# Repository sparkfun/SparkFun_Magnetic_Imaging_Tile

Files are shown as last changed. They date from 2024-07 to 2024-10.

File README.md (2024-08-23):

SparkFun Magnetic Imaging Tile - 8x8
========================================

SparkFun Magnetic Imaging Tile (https://www.sparkfun.com/products/26092)

[*SparkFun Magnetic Imaging Tile - 8x8 (SEN-26092)*](https://www.sparkfun.com/products/26092)

The Magnetic Imaging Tile uses an array of 64 hall effect sensors to convert magnetic fields to the visual spectrum. That's right! You can now see magnetic fields in real time! As is to be expected, there are caveats: the magnetic sensors used on the tile are some of the most sensitive on the market but you need to be within 1 to 2 centimeters of the tile to get a good image.

This is a board intended to function as a "magnetic field camera" to visualize magnetic fields.

This is an endorsed fork and collaboration of [Peter Jansen's work](https://hackaday.io/project/18518-iteration-8/log/91551-a-third-high-speed-magnetic-imager-tile). All credit goes to him! SparkX has re-designed the PCB for DFM and simplified some of the platform interfacing code.

### Version 3.0

The major advancement of v3.0 is a dramatic increase in the speed with which the tile data can be read out. ~2000 frames per second (fps) can be achieved which allows visualizing even quickly varying fields (e.g. those in a 60Hz transformer, or a moving motor). Version 3.0 reduces the size of the tile to an 8x8 grid of hall effect sensors (64 total), arrayed in a 4mm grid.  The boards is tile-able with up to 4 of the boards tileable with minimal borders to create a 16x16 array.

For more information (and a video of the v3.0 tile in use), please see:
https://hackaday.io/project/18518-iteration-8/log/91551-a-third-high-speed-magnetic-imager-tile-draft

Repository Contents
-------------------
* **.github/workflows** - YAML files used for GitHub Actions and GitHub Pages/mkdocs
* **/Hardware** - Eagle design files (.brd, .sch)
* **/Production** - Production panel files (.brd)
* **/Software** - Related software for the Magnetic Imaging Tile
* **/docs** - Online documentation files
  * **/assets** - Folder containing all the file assets used for product documentation
    * **/board_files** - Copy of design files used for product documentation
    * **/component_documentation** - Datasheets and manuals for hardware components
    * **/img** - Images for product documentation
  * **/github** - Files stating how to contribute and filing issues used for product documentation
  * **/javascript** - Folder containing custom javascript used for product documentation
  * **/stylesheet** - Folder containing CSS files used for product documentation
* **/overrides** - Customization files used for product documentation
  * **/.icons** - Icons used for GitHub used for product documentation
  * **./partials** - Used for product documentation

License Information
-------------------

This product is _**open source**_!

Please review the LICENSE.md file for license information.

If you have any questions or concerns on licensing, please contact technical support in our [SparkFun forums](https://community.sparkfun.com/c/community/general-chit-chat/37.)

Please use, reuse, and modify these files as you see fit. Please maintain attribution to SparkFun Electronics and release any derivative under the same license.

Disclaimer
-------------------

**DISCLAIMER OF WARRANTIES AND LIMITATION OF LIABILITY.**

UNLESS OTHERWISE SEPARATELY UNDERTAKEN BY THE LICENSOR, TO THE EXTENT POSSIBLE, THE LICENSOR OFFERS THE LICENSED MATERIAL AS-IS AND AS-AVAILABLE, AND MAKES NO REPRESENTATIONS OR WARRANTIES OF ANY KIND CONCERNING THE LICENSED MATERIAL, WHETHER EXPRESS, IMPLIED, STATUTORY, OR OTHER. THIS INCLUDES, WITHOUT LIMITATION, WARRANTIES OF TITLE, MERCHANTABILITY, FITNESS FOR A PARTICULAR PURPOSE, NON-INFRINGEMENT, ABSENCE OF LATENT OR OTHER DEFECTS, ACCURACY, OR THE PRESENCE OR ABSENCE OF ERRORS, WHETHER OR NOT KNOWN OR DISCOVERABLE. WHERE DISCLAIMERS OF WARRANTIES ARE NOT ALLOWED IN FULL OR IN PART, THIS DISCLAIMER MAY NOT APPLY TO YOU.

TO THE EXTENT POSSIBLE, IN NO EVENT WILL THE LICENSOR BE LIABLE TO YOU ON ANY LEGAL THEORY (INCLUDING, WITHOUT LIMITATION, NEGLIGENCE) OR OTHERWISE FOR ANY DIRECT, SPECIAL, INDIRECT, INCIDENTAL, CONSEQUENTIAL, PUNITIVE, EXEMPLARY, OR OTHER LOSSES, COSTS, EXPENSES, OR DAMAGES ARISING OUT OF THIS PUBLIC LICENSE OR USE OF THE LICENSED MATERIAL, EVEN IF THE LICENSOR HAS BEEN ADVISED OF THE POSSIBILITY OF SUCH LOSSES, COSTS, EXPENSES, OR DAMAGES. WHERE A LIMITATION OF LIABILITY IS NOT ALLOWED IN FULL OR IN PART, THIS LIMITATION MAY NOT APPLY TO YOU.

THE DISCLAIMER OF WARRANTIES AND LIMITATION OF LIABILITY PROVIDED ABOVE SHALL BE INTERPRETED IN A MANNER THAT, TO THE EXTENT POSSIBLE, MOST CLOSELY APPROXIMATES AN ABSOLUTE DISCLAIMER AND WAIVER OF ALL LIABILITY.

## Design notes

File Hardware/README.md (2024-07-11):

SparkFun <PRODUCT NAME> Design Files
=====================================

The .sch and .brd files hare are Eagle CAD schematic and PCB design files from SparkFun Electronics.
A freeware version of Autodesk Eagle can be found [here](https://www.autodesk.com/products/eagle/free-download).

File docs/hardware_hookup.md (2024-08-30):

### Connecting via PTH

For temporary connections to the PTHs, you could use IC hooks to test out the pins. However, you'll need to solder headers or wires of your choice to the board for a secure connection. You can choose between a combination of [header pins and jumper wires](https://learn.sparkfun.com/tutorials/how-to-solder-through-hole-soldering/all), or [stripping wire and soldering the wire](https://learn.sparkfun.com/tutorials/working-with-wire/all) directly to the board.

<div class="grid cards col-2" markdown>

-   <a href="https://learn.sparkfun.com/tutorials/how-to-solder-through-hole-soldering/all">
      <figure markdown>
        How to Solder: Through Hole Soldering
      </figure>
    </a>

    ---

    <a href="https://learn.sparkfun.com/tutorials/how-to-solder-through-hole-soldering/all">
      <b>How to Solder: Through Hole Soldering</b>
    </a>
<!-- ----------WHITE SPACE BETWEEN GRID CARDS---------- -->

-   <a href="https://learn.sparkfun.com/tutorials/working-with-wire/all">
      <figure markdown>
        Working with Wire
      </figure>
    </a>

    ---

    <a href="https://learn.sparkfun.com/tutorials/working-with-wire/all">
      <b>Working with Wire</b>
    </a>
<!-- ----------WHITE SPACE BETWEEN GRID CARDS---------- -->
</div>

For the scope of this tutorial, we will use right angle, male headers. Insert the right angle headers on the top side and solder the header pins from the bottom. Of course, you can also insert the right angle header so that the pins face toward the multiplexors similar to Peter's demo video.

<div style="text-align: center;">
  <table>
    <tr style="vertical-align:middle;">
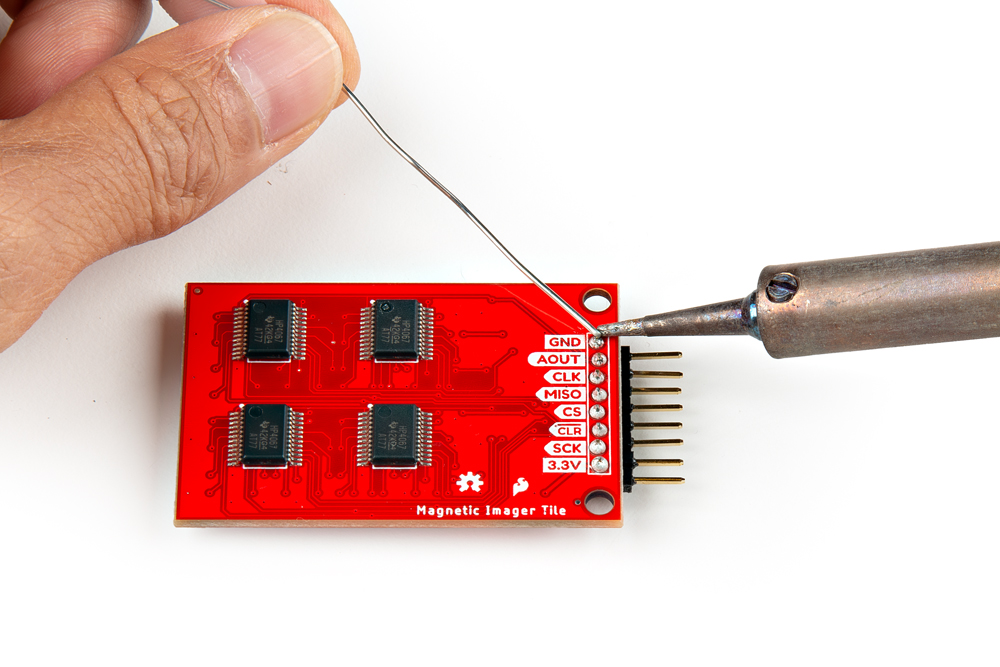
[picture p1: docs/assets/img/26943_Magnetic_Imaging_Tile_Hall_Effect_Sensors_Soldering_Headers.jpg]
Headers Being Soldered to the Magnetic Imaging Tile
     <td style="text-align: center; vertical-align: middle; border: solid 1px #cccccc;"></td>
    </tr>
    <tr style="vertical-align:middle;">
     <td style="text-align: center; vertical-align: middle; border: solid 1px #cccccc;"><i>Headers Being Soldered to the Magnetic Imaging Tile</i></td>
    </tr>
  </table>
</div>

<div style="text-align: center;">
    <table>
        <tr>
            <th style="text-align: center; border: solid 1px #cccccc;">Magnetic Imaging<br />Tile Pinout
            </th>
            <th style="text-align: center; border: solid 1px #cccccc;"> SAMD21 Pinout<br />(i.e. RedBoard Turbo, SAMD21 Mini, etc.)
            </th>
            <th style="text-align: center; border: solid 1px #cccccc;"> Teensy Pinout<br />(i.e. Teensy v3.1, v3.5, v4.0, v4.1, etc.)
            </th>
            <th style="text-align: center; border: solid 1px #cccccc;"> SAMD51 Pinout<br />(i.e. SAMD51 Thing Plus, etc.)
            </th>
        </tr>
        <tr>
            <td style="text-align: center; border: solid 1px #cccccc;" bgcolor="#DDDDDD"><font color="#000000">GND</font>
            </td>
            <td style="text-align: center; border: solid 1px #cccccc;" bgcolor="#DDDDDD"><font color="#000000">GND</font>
            </td>
            <td style="text-align: center; border: solid 1px #cccccc;" bgcolor="#DDDDDD"><font color="#000000">GND</font>
            </td>
            <td style="text-align: center; border: solid 1px #cccccc;" bgcolor="#DDDDDD"><font color="#000000">GND</font>
            </td>
        </tr>
        <tr>        
            <td style="text-align: center; border: solid 1px #cccccc;" bgcolor="#cce5ff"><font color="#000000">OUT</font>
            </td>
            <td style="text-align: center; border: solid 1px #cccccc;" bgcolor="#cce5ff"><font color="#000000">A1</font>
            </td>
            <td style="text-align: center; border: solid 1px #cccccc;" bgcolor="#cce5ff"><font color="#000000">A1</font>
            </td>
            <td style="text-align: center; border: solid 1px #cccccc;" bgcolor="#cce5ff"><font color="#000000">A1</font>
            </td>
        </tr>
        <tr>
            <td style="text-align: center; border: solid 1px #cccccc;" bgcolor="#fff3cd"><font color="#000000">SCK</font>
            <td style="text-align: center; border: solid 1px #cccccc;" bgcolor="#fff3cd"><font color="#000000">13</font>
            </td>
            <td style="text-align: center; border: solid 1px #cccccc;" bgcolor="#fff3cd"><font color="#000000">13</font>
            </td>
            <td style="text-align: center; border: solid 1px #cccccc;" bgcolor="#fff3cd"><font color="#000000">24</font>
            </td>
        </tr>
        <tr>
            <td style="text-align: center; border: solid 1px #cccccc;" bgcolor="#d4edda"><font color="#000000">MISO</font>
            </td>
            <td style="text-align: center; border: solid 1px #cccccc;" bgcolor="#d4edda"><font color="#000000">12</font>
            </td>
            <td style="text-align: center; border: solid 1px #cccccc;" bgcolor="#d4edda"><font color="#000000">12</font>
            </td>
            <td style="text-align: center; border: solid 1px #cccccc;" bgcolor="#d4edda"><font color="#000000">22</font>
            </td>
        </tr>
        <tr>
            <td style="text-align: center; border: solid 1px #cccccc;" bgcolor="#f2dede"><font color="#000000">CS</font>
            </td>
            <td style="text-align: center; border: solid 1px #cccccc;" bgcolor="#f2dede"><font color="#000000">10</font>
            </td>
            <td style="text-align: center; border: solid 1px #cccccc;" bgcolor="#f2dede"><font color="#000000">10</font>
            </td>
            <td style="text-align: center; border: solid 1px #cccccc;" bgcolor="#f2dede"><font color="#000000">10</font>
            </td>
        </tr>
        <tr>
            <td style="text-align: center; border: solid 1px #cccccc;" bgcolor="#ffffff"><font color="#000000">CLR</font>
            </td>
            <td style="text-align: center; border: solid 1px #cccccc;" bgcolor="#ffffff"><font color="#000000">8</font>
            </td>
            <td style="text-align: center; border: solid 1px #cccccc;" bgcolor="#ffffff"><font color="#000000">8</font>
            </td>
            <td style="text-align: center; border: solid 1px #cccccc;" bgcolor="#ffffff"><font color="#000000">5</font>
            </td>
        </tr>
        <tr>
            <td style="text-align: center; border: solid 1px #cccccc;" bgcolor="#ffdaaf"><font color="#000000">CLK</font>
            </td>
            <td style="text-align: center; border: solid 1px #cccccc;" bgcolor="#ffdaaf"><font color="#000000">9</font>
            </td>
            <td style="text-align: center; border: solid 1px #cccccc;" bgcolor="#ffdaaf"><font color="#000000">9</font>
            </td>
            <td style="text-align: center; border: solid 1px #cccccc;" bgcolor="#ffdaaf"><font color="#000000">9</font>
            </td>
        </tr>
        <tr>
            <td style="text-align: center; border: solid 1px #cccccc;" bgcolor="#f2dede"><font color="#000000">3.3V</font>
            </td>
            <td style="text-align: center; border: solid 1px #cccccc;" bgcolor="#f2dede"><font color="#000000">3V3</font>
            </td>
            <td style="text-align: center; border: solid 1px #cccccc;" bgcolor="#f2dede"><font color="#000000">3.3V</font>
            </td>
            <td style="text-align: center; border: solid 1px #cccccc;" bgcolor="#f2dede"><font color="#000000">3V3</font>
            </td>
        </tr>
    </table>
</div>

!!! note
    If you are using a development board with [updated SPI terminology](https://learn.sparkfun.com/tutorials/serial-peripheral-interface-spi/receiving-data), MISO may be labeled as POCI.

We will be using the RedBoard Turbo with female headers already installed on the board. For users that are using a different board, now would be a good time to solder headers or wires to the board. Below is an example with female headers soldered on the SAMD51 Thing Plus. Additionally, there are stackable headers soldered on the SAMD21 Mini Breakout so that the board can be inserted into a breadboard.

<div style="text-align: center;">
  <table>
    <tr style="vertical-align:middle;">
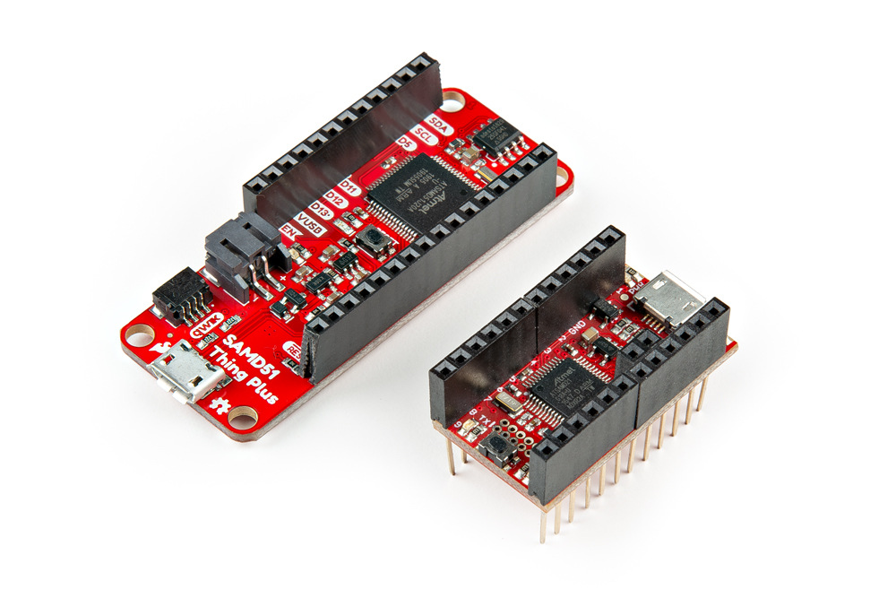
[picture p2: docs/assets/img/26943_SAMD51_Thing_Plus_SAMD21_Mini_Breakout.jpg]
Headers soldered on the SAMD51 Thing Plus and SAMD21 Mini Breakout
     <td style="text-align: center; vertical-align: middle; border: solid 1px #cccccc;"></td>
    </tr>
    <tr style="vertical-align:middle;">
     <td style="text-align: center; vertical-align: middle; border: solid 1px #cccccc;"><i>Headers soldered on the SAMD51 Thing Plus and SAMD21 Mini Breakout</i></td>
    </tr>
  </table>
</div>

### Connecting a Micrcontroller to the Magnetic Imaging Tile

We recommend using a microcontroller with sufficient RAM. While the example code can compile and function with Arduinos with an ATmega328P, the frames are limited. For the scope of the tutorial, we used a SAMD21. Of course, users can also use a Teensy and ChipKit as well.

Below is the Fritzing diagram of the RedBoard Turbo - SAMD21 connected to the Magnetic Imaging Tile.

<div style="text-align: center;">
  <table>
    <tr style="vertical-align:middle;">
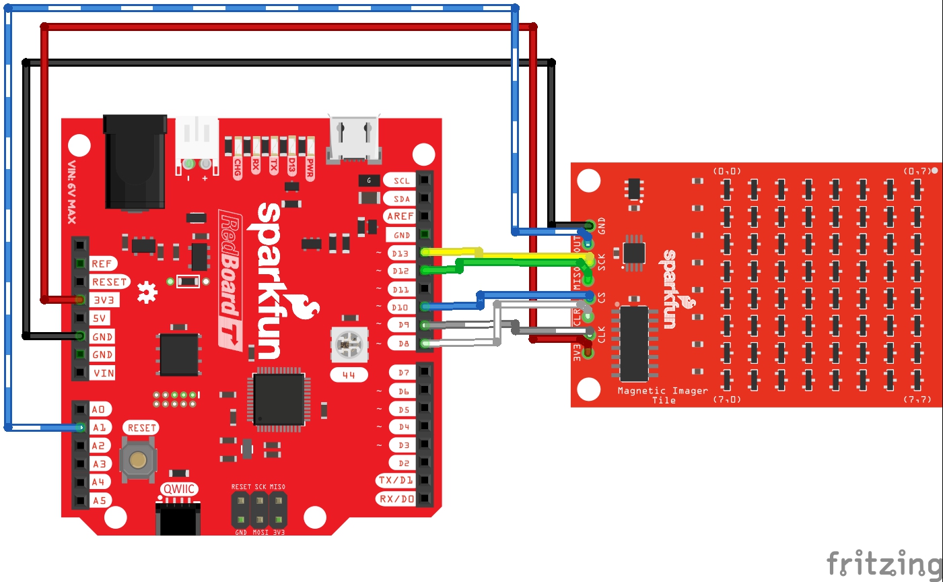
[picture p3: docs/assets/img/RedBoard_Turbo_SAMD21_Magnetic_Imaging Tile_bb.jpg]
Fritzing Diagram of RedBoard Turbo SAMD21 Connected to Magnetic Imaging Tile
     <td style="text-align: center; vertical-align: middle; border: solid 1px #cccccc;"></td>
    </tr>
    <tr style="vertical-align:middle;">
     <td style="text-align: center; vertical-align: middle; border: solid 1px #cccccc;"><i>Fritzing Diagram of RedBoard Turbo SAMD21 Connected to Magnetic Imaging Tile</i></td>
    </tr>
  </table>
</div>

After soldering headers to the Magnetic Imaging Tile, wire the board to the RedBoard Turbo using jumper wires. Then connect a micro-b USB cable to power and program the RedBoard Turbo.

<div style="text-align: center;">
  <table>
    <tr style="vertical-align:middle;">
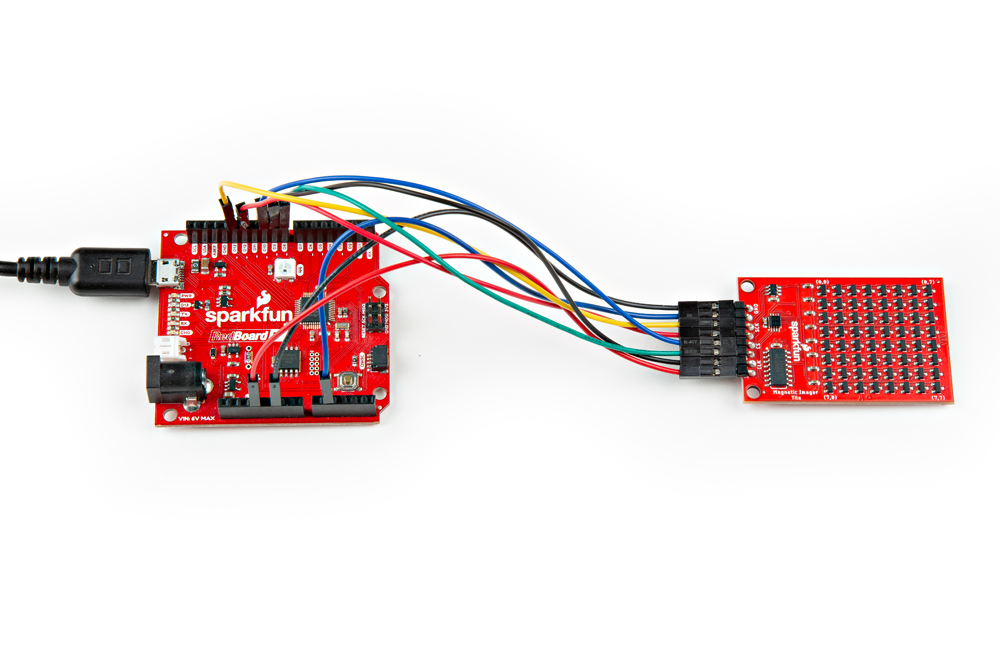
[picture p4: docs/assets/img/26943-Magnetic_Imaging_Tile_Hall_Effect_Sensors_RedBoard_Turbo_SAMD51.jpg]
RedBoard Turbo - SAMD21 Connected to Magnetic Imaging Tile
     <td style="text-align: center; vertical-align: middle; border: solid 1px #cccccc;"></td>
    </tr>
    <tr style="vertical-align:middle;">
     <td style="text-align: center; vertical-align: middle; border: solid 1px #cccccc;"><i>RedBoard Turbo - SAMD21 Connected to Magnetic Imaging Tile</i></td>
    </tr>
  </table>
</div>

You can also connected any SAMD21 to the Magnetic Imaging Tile. Below shows a Fritzing diagram of the SAMD21 Mini Breakout connected to the Magnetic Imaging Tile. When using other development boards, you may need to solder additional headers or wires to the board. Depending on the microcontroller, you may also need to redefine the pins in the Arduino example code in order to properly connect to the SPI port.

<div style="text-align: center;">
  <table>
    <tr style="vertical-align:middle;">
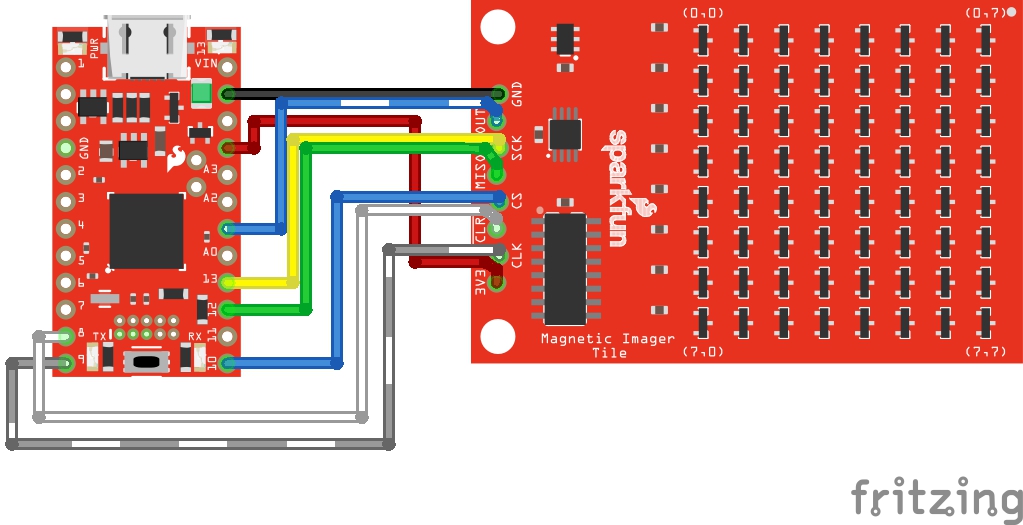
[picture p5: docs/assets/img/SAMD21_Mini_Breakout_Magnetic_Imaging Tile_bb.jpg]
Top View
     <td style="text-align: center; vertical-align: middle; border: solid 1px #cccccc;"></td>
    </tr>
    <tr style="vertical-align:middle;">
     <td style="text-align: center; vertical-align: middle; border: solid 1px #cccccc;"><i>Fritzing Diagram of SparkFun SAMD21 Mini Breakout Board Connected to Magnetic Imaging Tile</i></td>
    </tr>
  </table>
</div>

After soldering headers (or wires) on your microcontroller and Magnetic Imaging Tile, wire the boards together. The connect a micro-b USB cable to power and program the SAMD21 Mini Breakout.

<div style="text-align: center;">
  <table>
    <tr style="vertical-align:middle;">
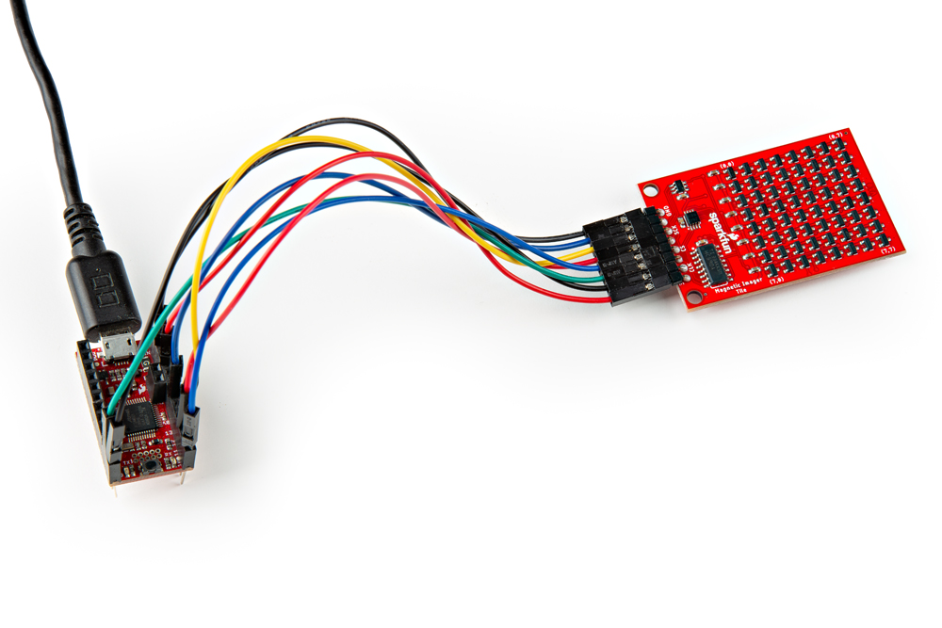
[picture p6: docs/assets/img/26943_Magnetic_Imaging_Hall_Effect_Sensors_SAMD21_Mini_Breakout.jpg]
SAMD21 Mini Breakout Connected to Magnetic Imaging Tile
     <td style="text-align: center; vertical-align: middle; border: solid 1px #cccccc;"></td>
    </tr>
    <tr style="vertical-align:middle;">
     <td style="text-align: center; vertical-align: middle; border: solid 1px #cccccc;"><i>SAMD21 Mini Breakout Connected to Magnetic Imaging Tile</i></td>
    </tr>
  </table>
</div>

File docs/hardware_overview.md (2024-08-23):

In this section, we will highlight the hardware and pins that are broken out on the SparkFun Magnetic Imaging Tile - 8x8. We'll refer to the "top" side of the board as the side with the 8x8 array of hall effect sensors. The "bottom" side of the board will be the side with the multiplexors. For more information, check out our [Resources and Going Further](../resources/) on the components used for the sensor.

<div style="text-align: center;">
  <table>
    <tr style="vertical-align:middle;">
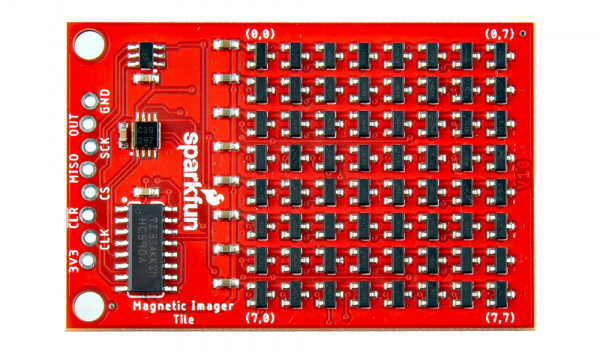
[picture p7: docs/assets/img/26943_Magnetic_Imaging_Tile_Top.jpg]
     <td style="text-align: center; vertical-align: middle; border: solid 1px #cccccc;"></td>
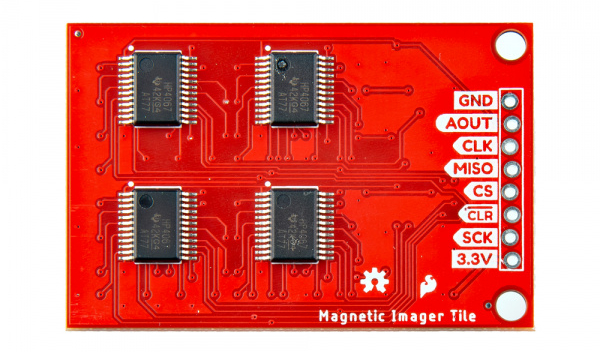
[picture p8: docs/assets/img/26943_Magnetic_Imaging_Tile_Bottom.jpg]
Bottom View
     <td style="text-align: center; vertical-align: middle; border: solid 1px #cccccc;"></td>
    </tr>
    <tr style="vertical-align:middle;">
     <td style="text-align: center; vertical-align: middle; border: solid 1px #cccccc;"><i>Top View</i></td>
     <td style="text-align: center; vertical-align: middle; border: solid 1px #cccccc;"><i>Bottom View</i></td>
    </tr>
  </table>
</div>

!!! note
    SparkX re-designed version 3.0's PCB for DFM and simplified some of the platform interfacing code. This design was transferred to SparkFun red and labeled as v1.0. Besides the color of the PCB and a few minor silkscreen changes, the boards are functionally the same.

    The major advancement of the current design (SparkX v3.0, SparkFun v1.0) is a dramatic increase in the speed with which the tile data can be read out. ~2000 frames per second (fps) can be achieved which allows visualizing even quickly varying fields (e.g. those in a 60Hz transformer, or a moving motor). Version 3.0 reduces the size of the tile to an 8x8 grid of hall effect sensors (64 total), arrayed in a 4mm grid. The boards is tile-able with up to 4 of the boards tile-able with minimal borders to create a 16x16 array.

!!! tip "What's with the zig zagging PTH's?"
    You may be wondering what is going on with the PTH. For those that have been around for a while, you might have noticed PTHs zig zagging on previous board designs. These offset PTHs are meant to "lock" header pins to the board to aid in soldering. For more information on the locking PTHs, check out the [Pete's "Sneaky Footprints"](https://www.sparkfun.com/tutorials/114)!

### Power

The 3.3V and ground are broken out on the edge of the board.

* **3V3** / **3.3V** &mdash; The 3.3V net is labeled as 3V3 or 3.3V. You can apply power to the board if you have a regulated voltage of 3.3V. Otherwise, you could power a separate device through the 3V3 PTH pin.
    * While the pin is labeled as 3.3V, you can also safely power the board with 5V as well. The components on the board can handle the voltage.
* **GND** &mdash; Of course, is the common, ground voltage (0V reference) for the system.

<div style="text-align: center;">
  <table>
    <tr style="vertical-align:middle;">
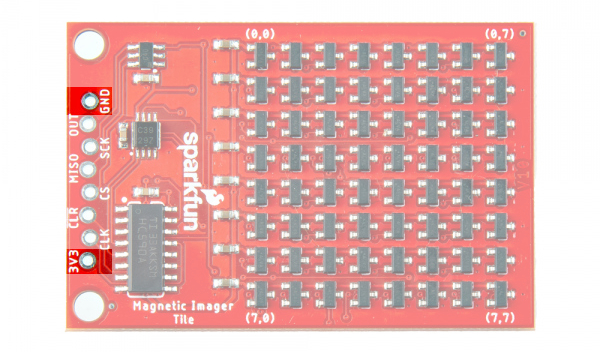
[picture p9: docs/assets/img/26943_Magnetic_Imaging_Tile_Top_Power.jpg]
Power and Ground Highlighted
     <td style="text-align: center; vertical-align: middle; border: solid 1px #cccccc;"></td>
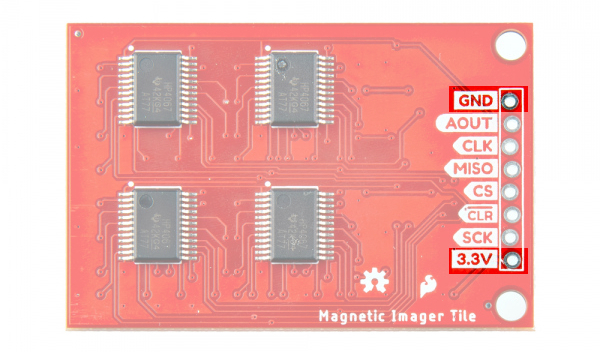
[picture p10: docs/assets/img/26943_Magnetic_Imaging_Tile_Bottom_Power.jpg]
Power and Ground Highlighted
     <td style="text-align: center; vertical-align: middle; border: solid 1px #cccccc;"></td>
    </tr>
    <tr style="vertical-align:middle;">
     <td style="text-align: center; vertical-align: middle; border: solid 1px #cccccc;" colspan="2"><i>Power and Ground Highlighted (Top & Bottom View)</i></td>
    </tr>
  </table>
</div>

### Hall Effect Sensors

The Magnetic Imaging Tile consists of 64x analog hall effect sensors arranged in an 8x8 grid. The specific hall effect sensor used is DRV5053VA with a sensitivity of -90mV/mT. The coordinates of each sensor is indicated by the silkscreen by the corners of the 8x8 array of hall effect sensors.

<div style="text-align: center;">
  <table>
    <tr style="vertical-align:middle;">
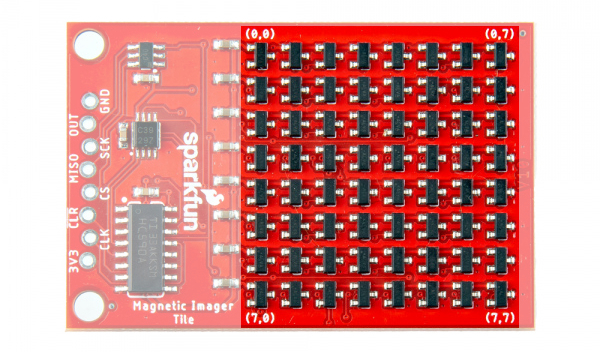
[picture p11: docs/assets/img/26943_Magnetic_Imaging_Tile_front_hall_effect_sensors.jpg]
Hall Effect Sensors Highlighted
     <td style="text-align: center; vertical-align: middle; border: solid 1px #cccccc;"></td>
    </tr>
    <tr style="vertical-align:middle;">
     <td style="text-align: center; vertical-align: middle; border: solid 1px #cccccc;"><i>Hall Effect sensors Highlighted/i></td>
    </tr>
  </table>
</div>

### Counter, Decoder, Muxes, and ADC

The circuit includes an SN74HC590A 8-bit binary counter (the 14-pin IC on the top of the board), SN74LVC1G139 decoder (the 8-pin IC on the top of the board), four CD74HC4067 multiplexors (the 4x ICs on the back of the board), and the AD7680 16-bit ADC (the 6-pin IC on the top of the board). Together (with some code loaded on a microcontroller), the components output the analog readings from the 64x hall effect sensors through SPI.

<div style="text-align: center;">
  <table>
    <tr style="vertical-align:middle;">
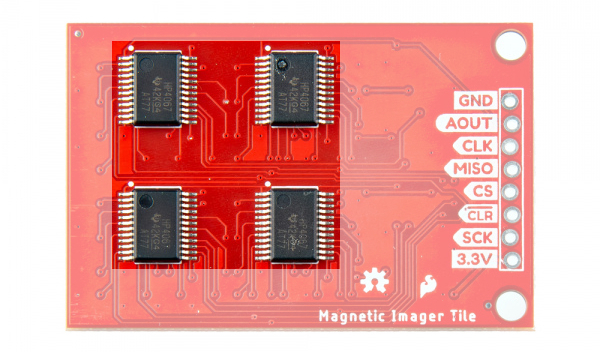
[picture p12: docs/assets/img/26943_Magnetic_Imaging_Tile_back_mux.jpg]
     <td style="text-align: center; vertical-align: middle; border: solid 1px #cccccc;"></td>
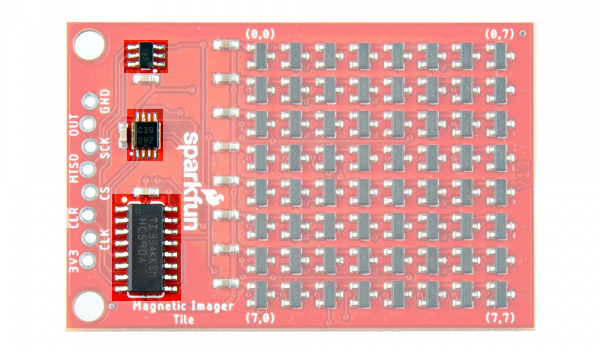
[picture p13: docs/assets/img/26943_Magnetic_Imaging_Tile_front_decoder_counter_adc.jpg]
     <td style="text-align: center; vertical-align: middle; border: solid 1px #cccccc;"></td>
    </tr>
    <tr style="vertical-align:middle;">
     <td style="text-align: center; vertical-align: middle; border: solid 1px #cccccc;"><i>Counter, Decoder, ADC Top View</i></td>
     <td style="text-align: center; vertical-align: middle; border: solid 1px #cccccc;"><i>Mux Bottom View</i></td>
    </tr>
  </table>
</div>

With a 16-bit ADC and a 3.3V range, this is approximately 50mV per bit. The Magnetic Imaging Tile is able to detect roughly +/- 0.5mT per bit. For our demo in the GIF we used a RedBoard Turbo with the SAMD21 to clock out the ADC data to the serial port at 115200. The serial is then parsed by a Processing sketch. This setup can achieve over 76 frames per second. With buffering the setup is capable of 200 fps. The ChipKit MAX32 is also supported and can achieve around 2,000fps. A faster processor should be able to achieve 1500fps (the 100kSPS limit of the ADC). The raw analog signal is also exposed. This allows processors that have built-in faster ADC to convert the signal directly. The theoretical limit of the DRV5053 is around 20,000 fps but would require a very fast ADC.

### SPI

The [SPI](https://learn.sparkfun.com/tutorials/serial-peripheral-interface-spi/all) port is broken out on the edge of the board. This connects to the AD7680 adc.

* **MISO** &mdash; Peripheral out, central in. The conversion from the AD7680 is provided on this output data pin.
* **CLK** (top side) / **SCK** (bottom side) &mdash; Serial clock input.
* <b><span STYLE="text-decoration:overline">CS</span></b> &mdash; Chip select. This is active when pulled low.

<div style="text-align: center;">
  <table>
    <tr style="vertical-align:middle;">
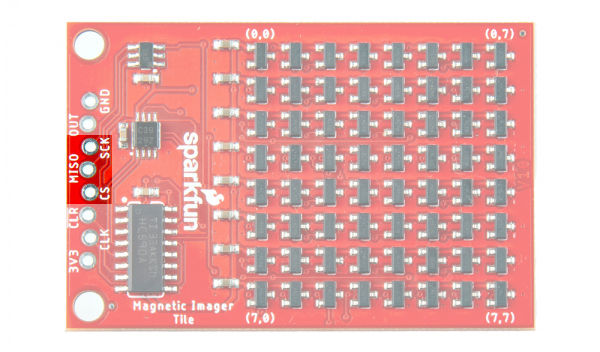
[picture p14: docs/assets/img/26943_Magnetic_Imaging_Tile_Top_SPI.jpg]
     <td style="text-align: center; vertical-align: middle; border: solid 1px #cccccc;"></td>
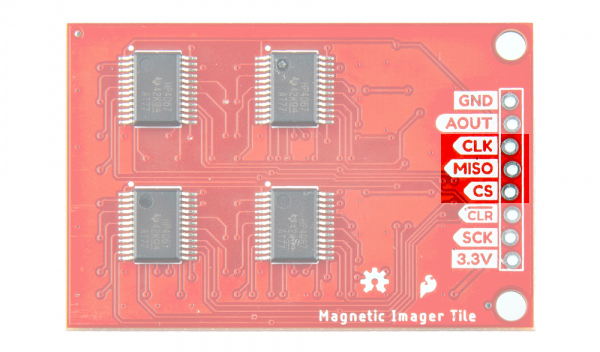
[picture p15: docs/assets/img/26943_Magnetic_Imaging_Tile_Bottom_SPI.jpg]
SPI Pins Highlighted - Bottom
     <td style="text-align: center; vertical-align: middle; border: solid 1px #cccccc;"></td>
    </tr>
    <tr style="vertical-align:middle;">
     <td style="text-align: center; vertical-align: middle; border: solid 1px #cccccc;" colspan="2"><i>SPI Pins Highlighted<br />(Top & Bottom View)</i></td>
  </table>
</div>

!!! note
    On the top side of the board, the serial clock is labeled as SCK. On the bottom side of the board, the serial clock in is labeled as CLK. Make sure to connect the serial clock located between the analog out and MISO pins.

### Additional Pins Broken Out

The following pins are also broken out on the board.

* <b><span STYLE="text-decoration:overline">CLR</span></b> &mdash; Clear counter input pin. This is connected to the SN74HC590AN.
* **CLK** (Top side) / **SCK** (bottom side) &mdash; Counter clock input. This is connected to the SN74HC590AN.
* **OUT** or **AOUT** &mdash; This is connected to the AD7680's analog input. This is connected to the multiplexors as well.

<div style="text-align: center;">
  <table>
    <tr style="vertical-align:middle;">
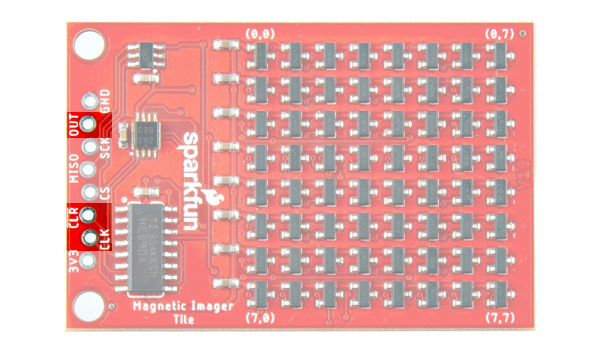
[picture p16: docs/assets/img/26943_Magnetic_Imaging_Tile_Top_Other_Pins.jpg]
SPI Pins Highlighted - Top
     <td style="text-align: center; vertical-align: middle; border: solid 1px #cccccc;"></td>
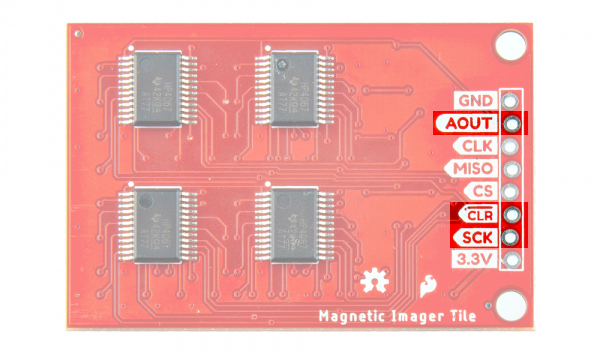
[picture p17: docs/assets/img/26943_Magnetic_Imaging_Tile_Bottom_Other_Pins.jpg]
Additional Pins Broken Out Highlighted - Bottom
     <td style="text-align: center; vertical-align: middle; border: solid 1px #cccccc;"></td>
    </tr>
    <tr style="vertical-align:middle;">
     <td style="text-align: center; vertical-align: middle; border: solid 1px #cccccc;" colspan="2"><i>Additional Pins Broken Out Highlighted<br />(Top & Bottom View)</i></td>
  </table>
</div>

!!! note
    On the top side of the board, the counter clock pin is labeled as CLK. On the bottom side of the board, the  counter clock in is labeled as SCK. Make sure to connect to the counter clock pin between the counter clear and 3.3V pin.

### Board Dimensions

The board is 1.35" x 2.05" (34.29mm x 52.07mm). There are 2x mounting holes by the PTHs. You can use 4-40 standoffs to mount the board to a panel or enclosure.

<div style="text-align: center;">
  <table>
    <tr style="vertical-align:middle;">
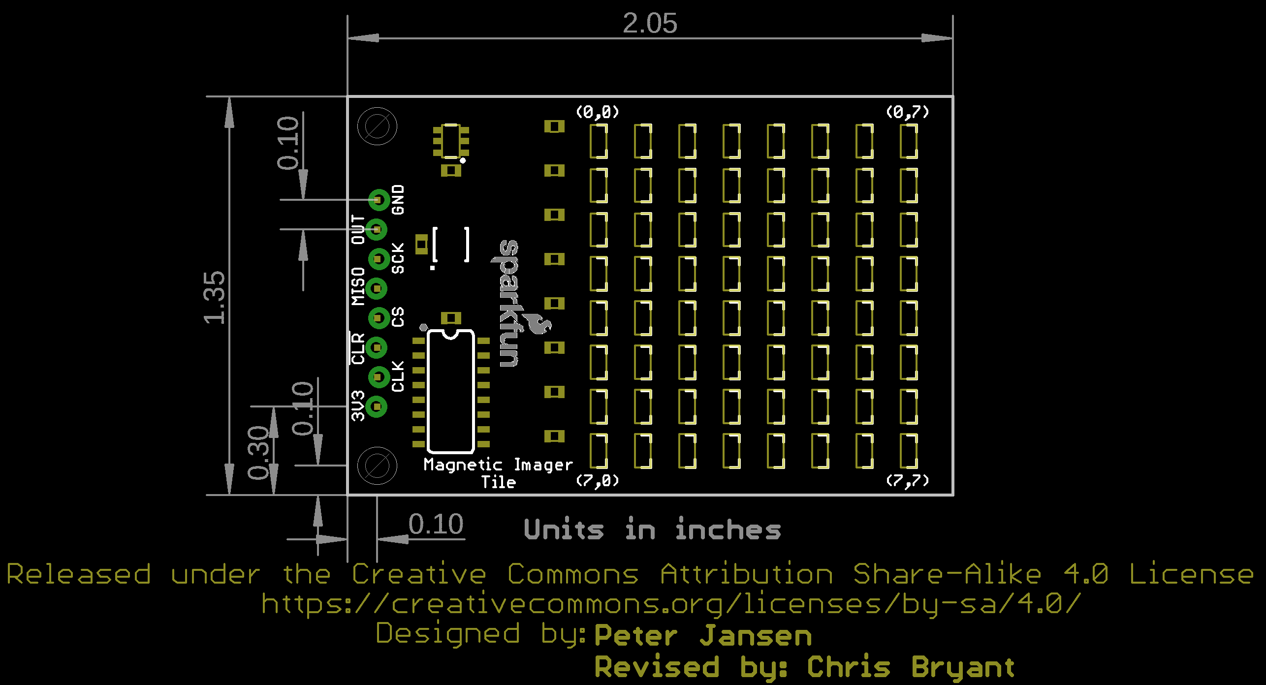
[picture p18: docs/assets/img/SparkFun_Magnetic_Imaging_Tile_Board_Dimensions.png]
Board Dimensions
     <td style="text-align: center; vertical-align: middle; border: solid 1px #cccccc;"></td>
    </tr>
    <tr style="vertical-align:middle;">
     <td style="text-align: center; vertical-align: middle; border: solid 1px #cccccc;"><i>Board Dimensions</i></td>
    </tr>
  </table>
</div>

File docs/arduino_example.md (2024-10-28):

This example is located in the Magnetic Imaging Tile's Hardware Repo. To grab it, go ahead and download or clone the [SparkFun Magnetic Imaging Tile hardware repo](https://github.com/sparkfun/SparkFun_Magnetic_Imaging_Tile/).

<div style="text-align: center"><a href="https://github.com/sparkfun/SparkFun_Magnetic_Imaging_Tile/archive/refs/heads/main.zip" target="download_magnetic_Imaging_tile_hardware_repo" class="md-button">Download Magnetic Imaging Tile Hardware Repo (ZIP)</a></div>

### Upload Arduino Example

After unzipping the compressed files, navigate to the hardware repo's folder and open the example: ... **SparkFun_Magnetic_Imaging_Tile** > **Software** > **arduino** > **Example1_Basic_Readings** > **Example1_Basic_Readings.ino**. This sketch listens for a character before parsing the data. For users using an Arduino microcontroller, select your board in the Tools menu (in our case the **SparkFun RedBoard Turbo**) and the correct Port it enumerated on.

You can also copy or paste the code as shown below. Then click "Upload".

``` c++
/*
 This basic example shows how to interface with the Magnetic Imaging Tile V3
 with a Chipkit MAX32, with data displayed via the serial port.
 Simple serial commands allow viewing the data in a serial console, or
 sending the data to a program on a host system (such as the accompanying
 Processing example) for display.

 The code primarily uses the internal ADC of the Chipkit MAX32, but
 (slow) code is also provided for using the AD7940 on the tile as
 well.  The speed of the ADC and I/O clocking is essentially the
 limiting factor in framerate, and this should be kept in mind
 when porting to other platforms (e.g. the Arduino Uno).

 The Chipkit MAX32 provides ~128K of RAM, which is enough for a
 short framebuffer (up to about 500 frames) when recording
 high-speed data.

 This code was written in MPIDE 0023-windows-20140316 .
*/

////Define where to pipe serial print statements
//#define terminal Serial //Use with Uno, SAMD51, Chipkit
#define terminal SerialUSB //Use with SAMD21

#define CS_INACTIVE  1
#define CS_ACTIVE    0

//Hardware connections
const byte PIN_ANALOG = A1;

//On Arduino Unos and Red Boards this is the SPI pinout

const byte PIN_CLR = 8;
const byte PIN_CLK = 9;
const byte AD7940_SPI_MISO = 12;
const byte AD7940_SPI_CS = 10;
const byte AD7940_SPI_CLK = 13;

// Pins for SAMD51
/*
const byte PIN_CLR = 5;
const byte PIN_CLK = 9;
const byte AD7940_SPI_MISO = 22;
const byte AD7940_SPI_CS = 10;
const byte AD7940_SPI_CLK = 24;
*/

// Frames
#if defined(__AVR_ATmega328P__) || defined(__AVR_ATmega168__)

//We have very limited RAM
#define MAX_BASE_FRAMES  2

#else

//Platforms like SAMD21, ChipKit, and Teensy have far more RAM
//#define MAX_BASE_FRAMES  500
//#define MAX_BASE_FRAMES  250
#define MAX_BASE_FRAMES  100
//#define _8BIT

#endif

#ifdef _8BIT
#define MAX_FRAMES      MAX_BASE_FRAMES*2
uint8_t frames[MAX_FRAMES][64];
#else
#define MAX_FRAMES      MAX_BASE_FRAMES
uint16_t frames[MAX_FRAMES][64];
#endif

// Frame variables
// Magnetic tile reading
int pixelOrder[] = {26, 27, 18, 19, 10, 11, 2, 3, 1, 0, 9, 8, 17, 16, 25, 24};
int subtileOrder[] = {0, 2, 1, 3};
int subtileOffset[] = {0, 4, 32, 36};
uint16_t frame[64];

int numFrames = 0;
int curFrame = 0;

#define MODE_IDLE          0
#define MODE_LIVE          1
#define MODE_HIGHSPEED1    2
#define MODE_HIGHSPEED2    3
#define MODE_HIGHSPEED3    4
#define MODE_HIGHSPEED4    5
#define MODE_PIXEL         6

int curMode = MODE_IDLE;

/*
   Analog Read
*/
int readMagnetometer() {
  //return 0;
  //return analogRead(PIN_ANALOG);
  //return readInternalADC();
  return readAD7940();
  //return read_ad7940();
}

// Take one measurement form the internal ADC
int readInternalADC() {
  int numSamples = 2;
  float sum = 0.0f;
  for (int i = 0; i < numSamples; i++) {
    int sensorValue = analogRead(PIN_ANALOG);
    sum += sensorValue;
  }
  sum /= numSamples;

  //return sensorValue;
  return int(floor(sum));
}

// Take one measurement from an external AD7940 14-bit ADC (SPI)
uint16_t readAD7940() {
  uint16_t value = 0;
  //uint16_t delay_time = 2;

  // Idle
  digitalWrite(AD7940_SPI_CS, HIGH);
  digitalWrite(AD7940_SPI_CLK, HIGH);

  // Enable
  digitalWrite(AD7940_SPI_CS, LOW);

  // Read 16 bits
  for (int i = 0; i < 16; i++) {
    char bit = digitalRead(AD7940_SPI_MISO);
    digitalWrite(AD7940_SPI_CLK, LOW);
    //    delayMicroseconds(delay_time);

    value = value << 1;
    value = value + (bit & 0x01);
    digitalWrite(AD7940_SPI_CLK, HIGH);
    //    delayMicroseconds(delay_time);
  }
  // Disable
  digitalWrite(AD7940_SPI_CS, HIGH);
  //  delayMicroseconds(delay_time);

  return value;
}

/*
   Magnetic Sensors
*/
void clearCounter() {
  digitalWrite(PIN_CLR, 0);
  //delay(10);
  digitalWrite(PIN_CLR, 1);
  //delay(10);
}

void incrementCounter() {
  digitalWrite(PIN_CLK, 1);
  //delay(1);
  digitalWrite(PIN_CLK, 0);
  //delay(1);
}

/*
   Capture one frame from imaging array
*/
void readTileFrame() {

  clearCounter();
  incrementCounter();

  for (int curSubtileIdx = 0; curSubtileIdx < 4; curSubtileIdx++) {
    for (int curIdx = 0; curIdx < 16; curIdx++) {
      // Read value
      int value = readMagnetometer();

      //terminal.println(value);
      //delay(10);

      // Store value in correct frame location
      int frameOffset = pixelOrder[curIdx] + subtileOffset[subtileOrder[curSubtileIdx]];
      //terminal.println(frameOffset);
      //delay(25);
      frame[frameOffset] = value;

      // Increment to next pixel
      incrementCounter();
    }
  }
}

// Display current frame on serial console
void displayCurrentFrame() {
  // Display frame
  //  terminal.println ("\nCurrent Frame");
  int idx = 0;
  for (int i = 0; i < 8; i++) {
    for (int j = 0; j < 8; j++) {
      terminal.print( frame[idx] );
      terminal.print( " " );
      idx += 1;
    }
    terminal.println("");
  }
  terminal.println("*");
}

// Record MAX_FRAMES, as fast as possible
void recordHighSpeedFrames(int frameDelayTime) {
  long startTime = millis();

  for (int curFrame = 0; curFrame < MAX_FRAMES; curFrame++) {
    // Read one frame
    readTileFrame();

    // Store frame
#ifdef _8BIT
    for (int a = 0; a < 64; a++) {
      frames[curFrame][a] = frame[a] >> 2;
    }
#else
    for (int a = 0; a < 64; a++) {
      frames[curFrame][a] = frame[a];
    }
#endif

    if (frameDelayTime > 0) {
      delay(frameDelayTime);
    }
  }

  long endTime = millis();
  terminal.print("Framerate: ");
  terminal.println((float)MAX_FRAMES / ((float)(endTime - startTime) / 1000.0f));
}

// Playback the high speed frames stored
void playbackHighSpeedFrames() {

  for (int curFrame = 0; curFrame < MAX_FRAMES; curFrame++) {
    // Display frame
    //    terminal.print ("\nFrame ");
    //    terminal.println (curFrame);

    int idx = 0;
    for (int i = 0; i < 8; i++) {
      for (int j = 0; j < 8; j++) {
        terminal.print( frames[curFrame][idx] );
        terminal.print( " " );
        idx += 1;
      }
      terminal.println("");
    }
    terminal.println("*");
    delay(50);
  }
}

long startTime = 0;

void setup() {
  // Setup pin modes
  pinMode(PIN_CLR, OUTPUT);
  pinMode(PIN_CLK, OUTPUT);

  // AD7940 ADC Pin modes
  pinMode(AD7940_SPI_CS, OUTPUT);
  pinMode(AD7940_SPI_CLK, OUTPUT);
  pinMode(AD7940_SPI_MISO, INPUT);

  // Setup initial states
  incrementCounter();
  clearCounter();

  // initialize serial:
  terminal.begin(115200);
  while(!terminal); //Wait for user to open this terminal. Useful for SAMD21 and boards that use CDC.

  terminal.println ("Initializing.... Press L (live) or H (high speed), 1, 2, 3, or S (idle)");

  clearCounter();
  incrementCounter();
  delay(100);

  startTime = millis();
}

void loop() {

  //Parse serial data (if any)
  if(terminal.available())
  {
    byte incoming = terminal.read();

    if (incoming == 'L') {
      terminal.println("Live");
      curMode = MODE_LIVE;

    } else if (incoming == 'H' || incoming == '1') {
      terminal.println("High-speed Save1");
      curMode = MODE_HIGHSPEED1;

    } else if (incoming == '2') {
      terminal.println("High-speed Save2 (1000hz)");
      curMode = MODE_HIGHSPEED2;

    } else if (incoming == '3') {
      terminal.println("High-speed Save3 (500hz)");
      curMode = MODE_HIGHSPEED3;

    } else if (incoming == '4') {
      terminal.println("High-speed Save4 (250hz)");
      curMode = MODE_HIGHSPEED4;

    } else if (incoming == 'S') {
      terminal.println("Idle");
      curMode = MODE_IDLE;

    } else if (incoming == 'P') {
      terminal.println("Read Pixel 0,0");
      curMode = MODE_PIXEL;
    }
  }

  /*
     Take action based on current mode
  */
  if (curMode == MODE_LIVE) {
    readTileFrame();
    displayCurrentFrame();

  } else if (curMode == MODE_HIGHSPEED1) {
    // Full/maximum speed
    recordHighSpeedFrames(0);
    playbackHighSpeedFrames();
    curMode = MODE_IDLE;

    terminal.println ("Initializing.... Press L (live) or H (high speed), 1, 2, 3, or S (idle)");

  } else if (curMode == MODE_HIGHSPEED2) {
    // ~1000Hz
    recordHighSpeedFrames(1);
    playbackHighSpeedFrames();
    curMode = MODE_IDLE;

    terminal.println ("Initializing.... Press L (live) or H (high speed), 1, 2, 3, or S (idle)");

  } else if (curMode == MODE_HIGHSPEED3) {
    // ~500Hz
    recordHighSpeedFrames(2);
    playbackHighSpeedFrames();
    curMode = MODE_IDLE;

    terminal.println ("Initializing.... Press L (live) or H (high speed), 1, 2, 3, or S (idle)");

  } else if (curMode == MODE_HIGHSPEED4) {
    // ~250Hz
    recordHighSpeedFrames(4);
    playbackHighSpeedFrames();
    curMode = MODE_IDLE;

    terminal.println ("Initializing.... Press L (live) or H (high speed), 1, 2, 3, or S (idle)");

  } else if (curMode == MODE_PIXEL) {
    //Read single pixel. Good for testing.

    curMode = MODE_IDLE;

    terminal.println ("Initializing.... Press L (live) or H (high speed), 1, 2, 3, or S (idle)");
  }

  //delay(10);
}

```

!!! note
    There is also an example for Diligent's chipKIT Max32! For users that are interested in using the board, the example code is in the **chipkit** folder.

!!! note
    For users that are using a SAMD51, you will need to adjust Serial:

    ``` c++
    #define terminal Serial //Use with Uno, SAMD51, Chipkit
    //#define terminal SerialUSB //Use with SAMD21
    ```

    You will also need to adjust the pin definitions:

    ``` c++
    //On Arduino Unos and Red Boards this is the SPI pinout
    /*
    const byte PIN_CLR = 8;
    const byte PIN_CLK = 9;
    const byte AD7940_SPI_MISO = 12;
    const byte AD7940_SPI_CS = 10;
    const byte AD7940_SPI_CLK = 13;
    */

    // Pins for SAMD51

    const byte PIN_CLR = 5;
    const byte PIN_CLK = 9;
    const byte AD7940_SPI_MISO = 22;
    const byte AD7940_SPI_CS = 10;
    const byte AD7940_SPI_CLK = 24;

    ```

After uploading the code, open the [Serial Monitor](https://learn.sparkfun.com/tutorials/terminal-basics) or terminal emulator of your choice with the baud rate set to **115200**. Enter a character (<kbd>L</kbd> , <kbd>H</kbd> , <kbd>1</kbd> , <kbd>2</kbd> , <kbd>3</kbd>, and <kbd>S</kbd> ) to select the mode. In this case, we set the mode to live.

<div style="text-align: center;">
  <table>
    <tr style="vertical-align:middle;">
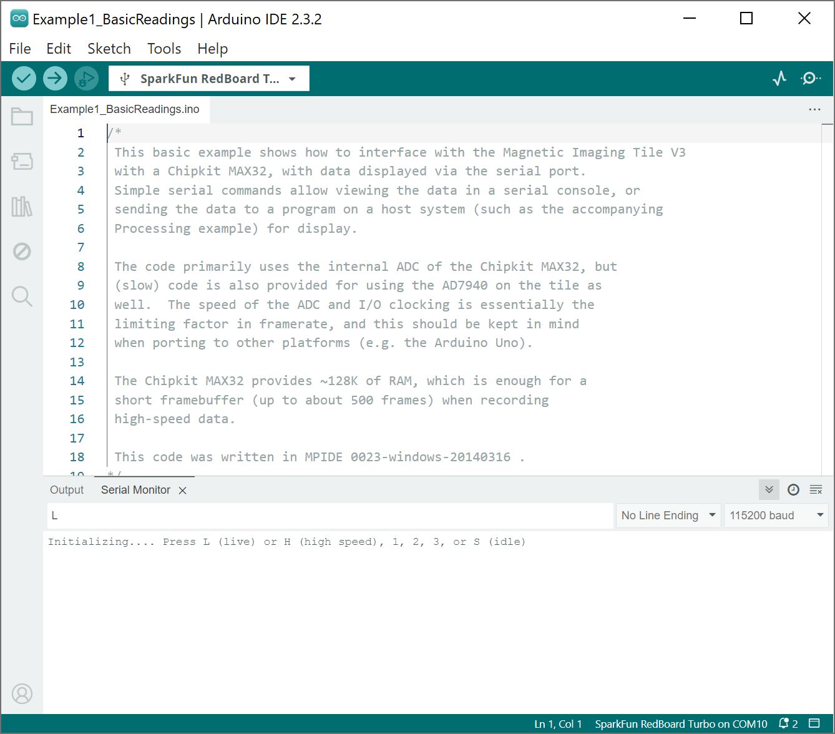
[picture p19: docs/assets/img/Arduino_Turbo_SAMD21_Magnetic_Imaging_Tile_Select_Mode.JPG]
Select Mode
     <td style="text-align: center; vertical-align: middle; border: solid 1px #cccccc;"></td>
    </tr>
    <tr style="vertical-align:middle;">
     <td style="text-align: center; vertical-align: middle; border: solid 1px #cccccc;"><i>Select Mode</i></td>
    </tr>
  </table>
</div>

The output will then begin output the readings.

<div style="text-align: center;">
  <table>
    <tr style="vertical-align:middle;">
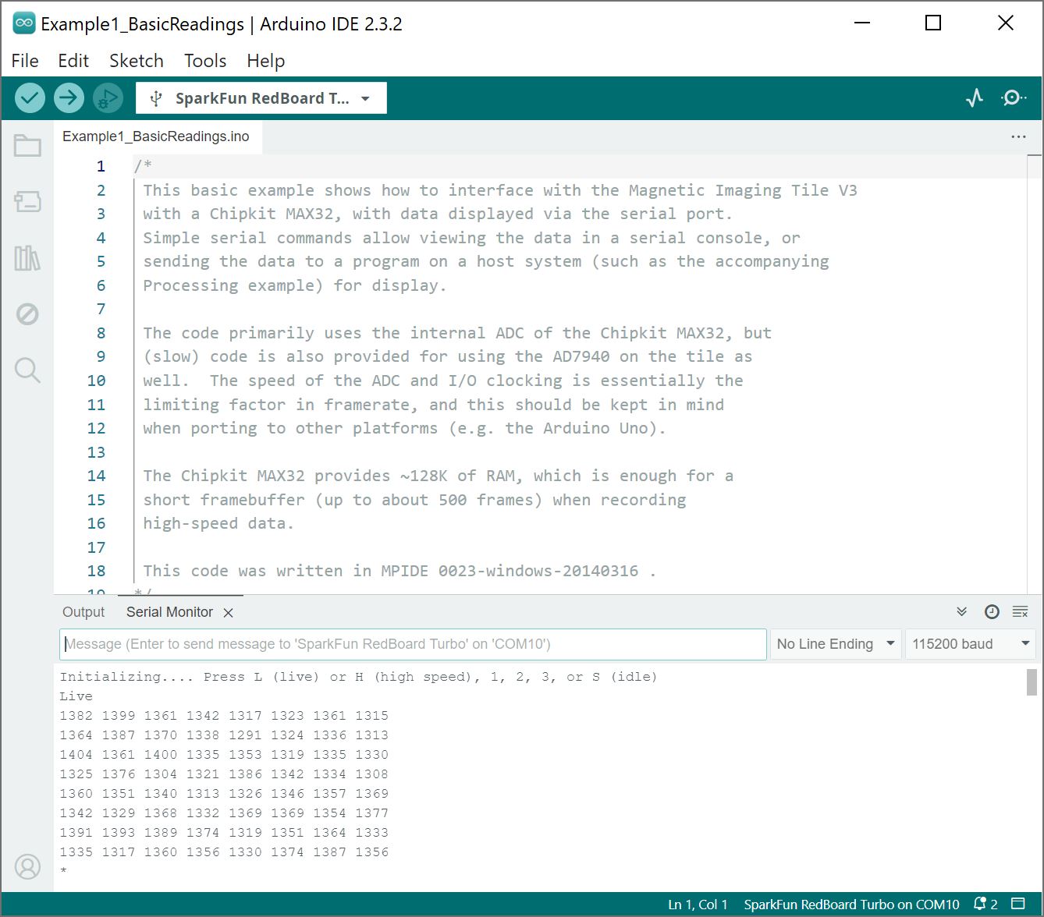
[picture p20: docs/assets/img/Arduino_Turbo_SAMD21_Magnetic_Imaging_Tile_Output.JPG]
Arduino IDE with Output, No Magnet
     <td style="text-align: center; vertical-align: middle; border: solid 1px #cccccc;"></td>
    </tr>
    <tr style="vertical-align:middle;">
     <td style="text-align: center; vertical-align: middle; border: solid 1px #cccccc;"><i>Arduino IDE with Output, No Magnet</i></td>
    </tr>
  </table>
</div>

Grab a magnet and place it near the sensor. In this case, the magnet was placed over the hall effect sensor at (0,0). The magnitude of the value will depend on the orientation of the magnet and the strength of the magnet. In this case, the magnitude was greater around (0,0) whenever the south pole was near the hall effect sensors.

<div style="text-align: center;">
  <table>
    <tr style="vertical-align:middle;">
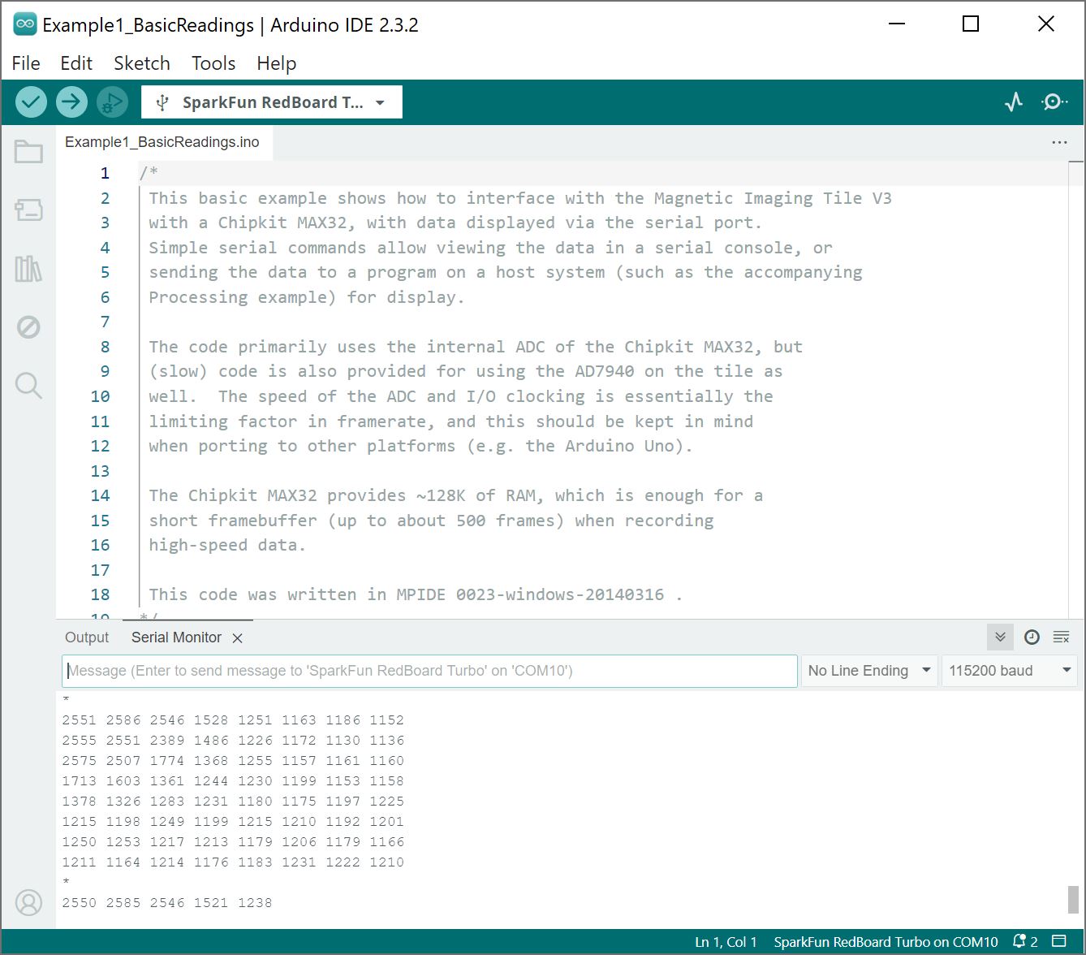
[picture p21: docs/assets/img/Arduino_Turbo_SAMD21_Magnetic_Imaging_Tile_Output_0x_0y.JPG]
Arduino IDE with Output, Magnet Over (0,0)
     <td style="text-align: center; vertical-align: middle; border: solid 1px #cccccc;"></td>
    </tr>
    <tr style="vertical-align:middle;">
     <td style="text-align: center; vertical-align: middle; border: solid 1px #cccccc;"><i>Arduino IDE with Output, Magnet Over (0,0)</i></td>
    </tr>    
  </table>
</div>

!!! tip
    For those that are interested in finding the polarity of your unlabeled magnet, there are [several tests to determine the polarity of each end of the magnet](https://www.google.com/search?q=determining+the+poles+of+a+magnet). One method is using a compass. If the north pole is pointing toward one end of the magnet, the end of the magnet is the south pole. If the south pole is pointing toward one end of the magnet, the end of the magnet is the north pole.

    If you know where the geographic north pole is, you can also attach the magnet to a string to determine its polarity. As the magnet is dangling from the string so that the poles are horizontal with respect to the floor. The south pole of the magnet will point toward the geographic north pole. Placing the magnet on a plastic lid over a bowl of water will also have the same results.

Rotating the magnet to the other pole and place it over (0,0) again. In this case, the value was lower around (0,0) whenever the north pole was near the hall effect sensors.

<div style="text-align: center;">
  <table>
    <tr style="vertical-align:middle;">
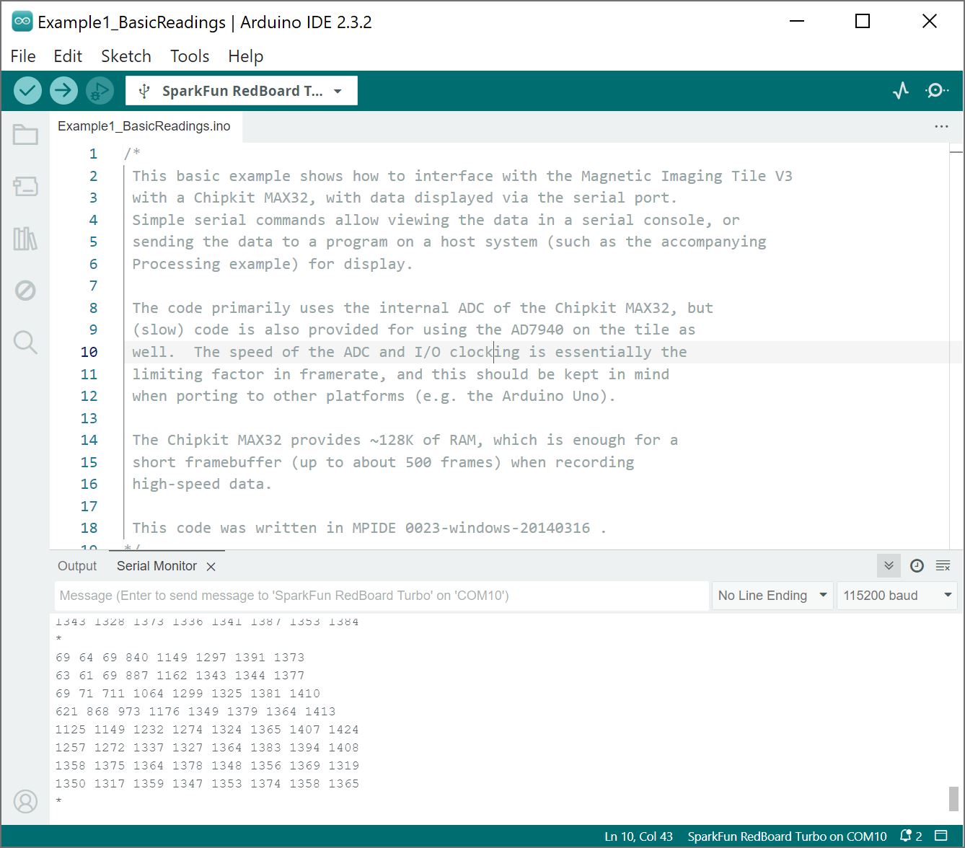
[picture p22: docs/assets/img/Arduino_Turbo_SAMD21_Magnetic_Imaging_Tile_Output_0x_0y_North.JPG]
Arduino IDE with Output, Magnet North Over (0,0)
     <td style="text-align: center; vertical-align: middle; border: solid 1px #cccccc;"></td>
    </tr>
    <tr style="vertical-align:middle;">
     <td style="text-align: center; vertical-align: middle; border: solid 1px #cccccc;"><i>Arduino IDE with Output, Magnet North Over (0,0)</i></td>
    </tr>   
  </table>
</div>

Try moving the magnet to a different location near the array of hall effect sensors to track the magnetic field. In this case, we moved it to (7,7). If you inspect the values, you will notice that the magnet was also rotated so that the south pole was over the hall effect sensors. In this case, the magnitude was greater around (7,7).

<div style="text-align: center;">
  <table>
    <tr style="vertical-align:middle;">
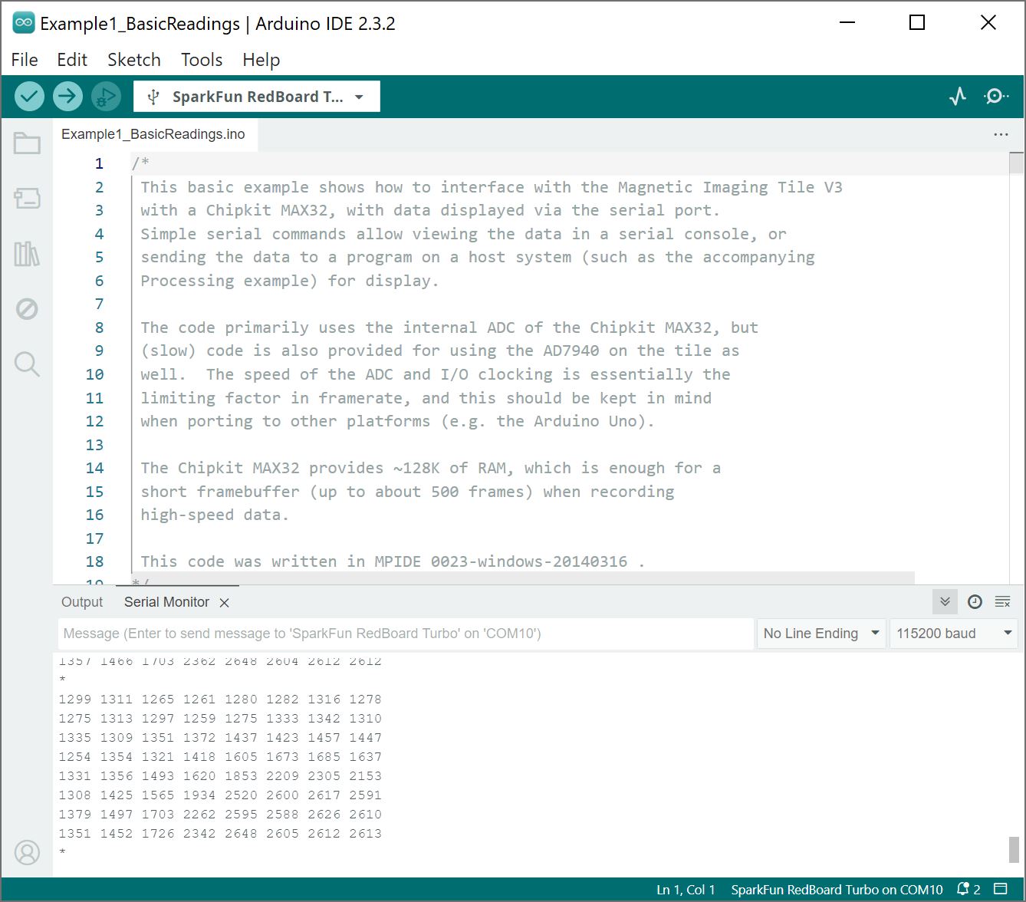
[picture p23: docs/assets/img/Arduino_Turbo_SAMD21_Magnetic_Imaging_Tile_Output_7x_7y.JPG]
Arduino IDE with Output, Magnet Over (7,7)
     <td style="text-align: center; vertical-align: middle; border: solid 1px #cccccc;"></td>
    </tr>
    <tr style="vertical-align:middle;">
     <td style="text-align: center; vertical-align: middle; border: solid 1px #cccccc;"><i>Arduino IDE with Output, Magnet Over (7,7)</i></td>
    </tr>
  </table>
</div>

Rotating the magnet back to the north pole at (7,7) will result in the opposite effect where the values were lower around (0,0). This is similar to what was observed earlier.

<div style="text-align: center;">
  <table>
    <tr style="vertical-align:middle;">
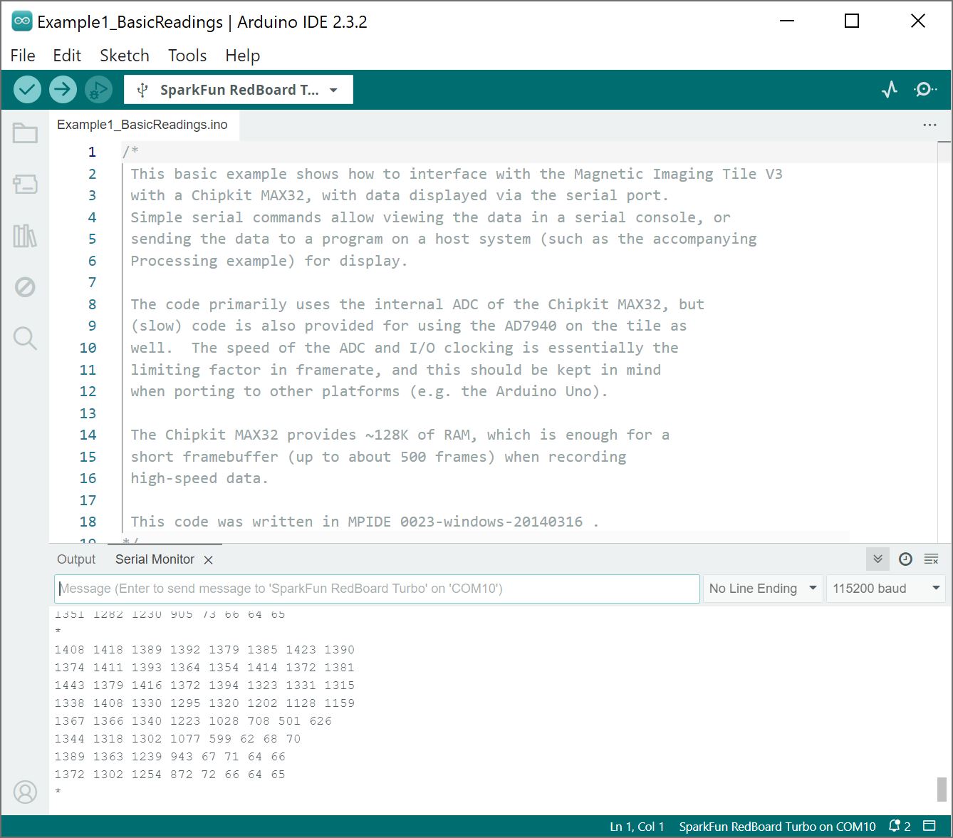
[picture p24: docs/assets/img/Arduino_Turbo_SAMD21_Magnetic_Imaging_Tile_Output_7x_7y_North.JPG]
Arduino IDE with Output, Magnet North Over 7x,7y
     <td style="text-align: center; vertical-align: middle; border: solid 1px #cccccc;"></td>
    </tr>
    <tr style="vertical-align:middle;">
     <td style="text-align: center; vertical-align: middle; border: solid 1px #cccccc;"><i>Arduino IDE with Output, Magnet North Over (7,7)</i></td>
    </tr>
  </table>
</div>

Looking for a more visual output? We'll use this example loaded on the Arduino to visualize the output through the Processing IDE!

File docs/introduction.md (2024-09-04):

The [SparkFun Magnetic Imaging Tile - 8x8](https://www.sparkfun.com/products/26092) uses an array of 64 hall effect sensors to convert magnetic fields to the visual spectrum. That's right! You can now see magnetic fields in real time! As is to be expected, there are caveats: the magnetic sensors used on the tile are some of the most sensitive on the market but you need to be within 1 to 2 centimeters of the tile to get a good image.

<div class="grid cards" style="width:500px; margin: 0 auto;" markdown>

-   <a href="https://www.sparkfun.com/products/26092">
      <figure markdown>
        SparkFun Magnetic Imaging Tile - 8x8
      </figure>
    </a>

    ---

    <a href="https://www.sparkfun.com/products/26092">
      <b>SparkFun Magnetic Imaging Tile - 8x8</b>
      <br />
      SEN-26092
      <br />
      <center>[Purchase from SparkFun :fontawesome-solid-cart-plus:](https://www.sparkfun.com/products/26092){ .md-button .md-button--primary }</center>
    </a>
</div>

The demo shown in the animated GIFs don't quite give the Magnetic Imaging Tile justice! The frame rate of gifs is too low! Please see [Peter's demo video](https://www.youtube.com/watch?v=vxOuoWygxy0) for some amazing visuals.

<div style="text-align: center;">
  <iframe width="560" height="315" src="https://www.youtube.com/embed/vxOuoWygxy0?si=k2MAxdDgUQiwu3nT" title="YouTube video player" frameborder="0" allow="accelerometer; autoplay; clipboard-write; encrypted-media; gyroscope; picture-in-picture; web-share" referrerpolicy="strict-origin-when-cross-origin" allowfullscreen></iframe>
</div>

In this tutorial, we'll go over the hardware and how to hookup the sensor to an Arduino. We will also go over an Arduino and Processing example to get started.

### Required Materials

To follow along with this tutorial, you will need the following materials. You may not need everything though depending on what you have. Add it to your cart, read through the guide, and adjust the cart as necessary.

<div class="grid cards col-4" markdown>

<!-- ----------WHITE SPACE BETWEEN PRODUCTS---------- -->
-   <a href="https://www.sparkfun.com/products/10215">
      <figure markdown>
        USB Micro-B Cable - 6 Foot
      </figure>
    </a>

    ---

    <a href="https://www.sparkfun.com/products/10215">
      <b>USB Micro-B Cable - 6 Foot</b>
      <br />
      CAB-10215
    </a>
<!-- ----------WHITE SPACE BETWEEN PRODUCTS---------- -->
-   <a href="https://www.sparkfun.com/products/14812">
      <figure markdown>
        SparkFun RedBoard Turbo - SAMD21 Development Board
      </figure>
    </a>

    ---

    <a href="https://www.sparkfun.com/products/14812">
      <b>SparkFun RedBoard Turbo - SAMD21 Development Board</b>
      <br />
      DEV-14812
    </a>
<!-- ----------WHITE SPACE BETWEEN PRODUCTS---------- -->
-   <a href="https://www.sparkfun.com/products/26092">
      <figure markdown>
        SparkFun Magnetic Imaging Tile - 8x8
      </figure>
    </a>

    ---

    <a href="https://www.sparkfun.com/products/26092">
      <b>SparkFun Magnetic Imaging Tile - 8x8</b>
      <br />
      SEN-26092
    </a>
<!-- ----------WHITE SPACE BETWEEN PRODUCTS---------- -->
-   <a href="https://www.sparkfun.com/products/553">
      <figure markdown>
        Break Away Male Headers - Right Angle
      </figure>
    </a>

    ---

    <a href="https://www.sparkfun.com/products/553">
      <b>Break Away Male Headers - Right Angle</b>
      <br />
      PRT-00553
    </a>
<!-- ----------WHITE SPACE BETWEEN PRODUCTS---------- -->
-   <a href="https://www.sparkfun.com/products/9140">
      <figure markdown>
        Jumper Wires Premium 6
      <br />
      PRT-09140
    </a>
<!-- ----------WHITE SPACE BETWEEN PRODUCTS---------- -->
</div>

### Other Microcontrollers

We'll be using the RedBoard Turbo - SAMD21 Development Board for the examples in this tutorial. The Arduino code also compatible with SAMD microcontrollers like the SAMD21 Dev Breakout, SAMD21 Mini Breakout, and SparkFun Thing Plus - SAMD51. You can also use a Teensy as well. Just make sure to solder headers (or wires) to the board and include a compatible USB cable with the development board.

<div class="grid cards col-4" markdown>
<!-- ----------WHITE SPACE BETWEEN PRODUCTS---------- -->
-   <a href="https://www.sparkfun.com/products/13672">
      <figure markdown>
        SparkFun SAMD21 Dev Breakout
      </figure>
    </a>

    ---

    <a href="https://www.sparkfun.com/products/13672">
      <b>SparkFun SAMD21 Dev Breakout</b>
      <br />
      DEV-13672
    </a>
<!-- ----------WHITE SPACE BETWEEN PRODUCTS---------- -->
-   <a href="https://www.sparkfun.com/products/13664">
      <figure markdown>
        SparkFun SAMD21 Mini Breakout
      </figure>
    </a>

    ---

    <a href="https://www.sparkfun.com/products/13664">
      <b>SparkFun SAMD21 Mini Breakout</b>
      <br />
      DEV-13664
    </a>
<!-- ----------WHITE SPACE BETWEEN PRODUCTS---------- -->
-   <a href="https://www.sparkfun.com/products/16997">
      <figure markdown>
        Teensy 4.0 (Headers)
      </figure>
    </a>

    ---

    <a href="https://www.sparkfun.com/products/16997">
      <b>Teensy 4.0 (Headers)</b>
      <br />
      DEV-16997
    </a>
<!-- ----------WHITE SPACE BETWEEN PRODUCTS---------- -->
-   <a href="https://www.sparkfun.com/products/14713">
      <figure markdown>
        SparkFun Thing Plus - SAMD51
      </figure>
    </a>

    ---

    <a href="https://www.sparkfun.com/products/14713">
      <b>SparkFun Thing Plus - SAMD51</b>
      <br />
      DEV-14713
    </a>
<!-- ----------WHITE SPACE BETWEEN PRODUCTS---------- -->
</div>

While the ChipKit MAX32 is not listed in the SparkFun catalog, you can also use it with the Magnetic Imaging Tile.

### Tools

You will need a soldering iron, solder, and [general soldering accessories](https://www.sparkfun.com/categories/49) for a secure connection when using the plated through holes.

<div class="grid cards col-4" markdown>

-   <a href="https://www.sparkfun.com/products/14456">
      <figure markdown>
        Soldering Iron - 60W (Adjustable Temperature)
      </figure>
    </a>

    ---

    <a href="https://www.sparkfun.com/products/14456">
      <b>Soldering Iron - 60W (Adjustable Temperature)</b>
      <br />
      TOL-14456
    </a>
<!-- ----------WHITE SPACE BETWEEN PRODUCTS---------- -->
-   <a href="https://www.sparkfun.com/products/9163">
      <figure markdown>
        Solder Lead Free - 15-gram Tube
      </figure>
    </a>

    ---

    <a href="https://www.sparkfun.com/products/9163">
      <b>Solder Lead Free - 15-gram Tube</b>
      <br>
      TOL-09163
    </a>
<!-- ----------WHITE SPACE BETWEEN PRODUCTS---------- -->
-   <a href="https://www.sparkfun.com/products/11375">
      <figure markdown>
        Hook-Up Wire - Assortment (Stranded, 22 AWG)
      </figure>
    </a>

    ---

    <a href="https://www.sparkfun.com/products/11375">
      <b>Hook-Up Wire - Assortment (Stranded, 22 AWG)</b>
      <br />
      PRT-11375
    </a>
<!-- ----------WHITE SPACE BETWEEN PRODUCTS---------- -->
-   <a href="https://www.sparkfun.com/products/12630">
      <figure markdown>
        Wire Strippers - 30AWG (Hakko)
      </figure>
    </a>

    ---

    <a href="https://www.sparkfun.com/products/12630">
      <b>Wire Strippers - 30AWG (Hakko)</b>
      <br />
      TOL-12630
    </a>
<!-- ----------WHITE SPACE BETWEEN PRODUCTS---------- -->
-   <a href="https://www.sparkfun.com/products/11952">
      <figure markdown>
        Flush Cutters - Hakko
      </figure>
    </a>

    ---

    <a href="https://www.sparkfun.com/products/11952">
      <b>Flush Cutters - Hakko</b>
      <br />
      TOL-11952
    </a>
<!-- ----------WHITE SPACE BETWEEN PRODUCTS---------- -->
</div>

### Prototyping Accessories

Depending on your setup, you may want to use IC hooks for a temporary connection. However, you will want to solder header pins to connect devices to the plated through holes for a secure connection. We opted for right angle headers for the SparkFun Magnetic Imaging Tile as well as M/F jumpers to connect to the SparkFun RedBoard Turbo - SAMD21 Development Board to reduce the amount of soldering.

<div class="grid cards col-4" markdown>

-   <a href="https://www.sparkfun.com/products/12002">
      <figure markdown>
        Breadboard - Self-Adhesive (White)
      </figure>
    </a>

    ---

    <a href="https://www.sparkfun.com/products/12002">
      <b>Breadboard - Self-Adhesive (White)</b>
      <br />
      PRT-12002
    </a>
<!-- ----------WHITE SPACE BETWEEN PRODUCTS---------- -->
-   <a href="https://www.sparkfun.com/products/9741">
      <figure markdown>
        IC Hook with Pigtail
      </figure>
    </a>

    ---

    <a href="https://www.sparkfun.com/products/9741">
      <b>IC Hook with Pigtail</b>
      <br>
      CAB-09741
    </a>
<!-- ----------WHITE SPACE BETWEEN PRODUCTS---------- -->
-   <a href="https://www.sparkfun.com/products/553">
      <figure markdown>
        Break Away Male Headers - Right Angle
      </figure>
    </a>

    ---

    <a href="https://www.sparkfun.com/products/553">
      <b>Break Away Male Headers - Right Angle</b>
      <br />
      PRT-00553
    </a>
<!-- ----------WHITE SPACE BETWEEN PRODUCTS---------- -->
-   <a href="https://www.sparkfun.com/products/9140">
      <figure markdown>
        Jumper Wires Premium 6
      <br />
      PRT-09140
    </a>
<!-- ----------WHITE SPACE BETWEEN PRODUCTS---------- -->
</div>

### Suggested Reading

If you aren’t familiar with the following concepts, we also recommend checking out a few of these tutorials before continuing.

<div class="grid cards col-4" markdown>

-   <a href="https://learn.sparkfun.com/tutorials/how-to-solder-through-hole-soldering">
      <figure markdown>
        How to Solder: Through-Hole Soldering
      </figure>
    </a>

    ---

    <a href="https://learn.sparkfun.com/tutorials/how-to-solder-through-hole-soldering">
      <b>How to Solder: Through-Hole Soldering</b>
    </a>
<!-- ----------WHITE SPACE BETWEEN GRID CARDS---------- -->
-   <a href="https://learn.sparkfun.com/tutorials/installing-arduino-ide">
      <figure markdown>
        Installing Arduino IDE
      </figure>
    </a>

    ---

    <a href="https://learn.sparkfun.com/tutorials/installing-arduino-ide">
      <b>Installing Arduino IDE</b>
    </a>
<!-- ----------WHITE SPACE BETWEEN GRID CARDS---------- -->
-   <a href="https://learn.sparkfun.com/tutorials/redboard-turbo-hookup-guide">
      <figure markdown>
        RedBoard Turbo Hookup Guide
      </figure>
    </a>

    ---

    <a href="https://learn.sparkfun.com/tutorials/redboard-turbo-hookup-guide">
      <b>RedBoard Turbo Hookup Guide</b>
    </a>
<!-- ----------WHITE SPACE BETWEEN GRID CARDS---------- -->
-   <a href="https://learn.sparkfun.com/tutorials/installing-board-definitions-in-the-arduino-ide">
      <figure markdown>
        Installing Board Definitions in the Arduino IDE
      </figure>
    </a>

    ---

    <a href="https://learn.sparkfun.com/tutorials/installing-board-definitions-in-the-arduino-ide">
      <b>Installing Board Definitions in the Arduino IDE</b>
    </a>
<!-- ----------WHITE SPACE BETWEEN GRID CARDS---------- -->
-   <a href="https://learn.sparkfun.com/tutorials/serial-peripheral-interface-spi">
      <figure markdown>
        Serial Peripheral Interface (SPI)
      </figure>
    </a>

    ---

    <a href="https://learn.sparkfun.com/tutorials/serial-peripheral-interface-spi">
      <b>Serial Peripheral Interface (SPI)</b>
    </a>
<!-- ----------WHITE SPACE BETWEEN GRID CARDS---------- -->
-   <a href="https://learn.sparkfun.com/tutorials/logic-levels">
      <figure markdown>
        Logic Levels
      </figure>
    </a>

    ---

    <a href="https://learn.sparkfun.com/tutorials/logic-levels">
      <b>Logic Levels</b>
    </a>
<!-- ----------WHITE SPACE BETWEEN GRID CARDS---------- -->
-   <a href="https://learn.sparkfun.com/tutorials/analog-vs-digital">
      <figure markdown>
        Analog vs. Digital
      </figure>
    </a>

    ---

    <a href="https://learn.sparkfun.com/tutorials/analog-vs-digital">
      <b>Analog vs. Digital</b>
    </a>
<!-- ----------WHITE SPACE BETWEEN GRID CARDS---------- -->
</div>

!!! note
    This is a collaboration with Peter Jansen of the "[Open Source Science Tricorder Project](http://www.tricorderproject.org/)". All credit goes to him! You can read about his work on the project on [Hack A Day](https://hackaday.io/project/18518-iteration-8/log/91551-a-third-high-speed-magnetic-imager-tile).

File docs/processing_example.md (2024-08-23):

This example also is located in the Magnetic Imaging Tile's Hardware Repo. To grab it, go ahead and download or clone the [SparkFun Magnetic Imaging Tile hardware repo](https://github.com/sparkfun/SparkFun_Magnetic_Imaging_Tile/) if you have not already.

<div style="text-align: center"><a href="https://github.com/sparkfun/SparkFun_Magnetic_Imaging_Tile/archive/refs/heads/main.zip" target="download_magnetic_Imaging_tile_hardware_repo" class="md-button">Download Magnetic Imaging Tile Hardware Repo (ZIP)</a></div>

### Upload Arduino Example

Processing listens for serial data, so we'll need to get our microcontroller to produce serial data that makes sense to Processing. In this case, we will be using the [Arduino example to output basic readings from earlier](../arduino_example/).

<div style="text-align: center;">
  <table>
    <tr style="vertical-align:middle;">
     <td style="text-align: center; vertical-align: middle; border: solid 1px #cccccc;"><a href="../assets/img/Arduino_Turbo_SAMD21_Magnetic_Imaging_Tile_Output.JPG">Arduino IDE with Output</a></td>
    </tr>
    <tr style="vertical-align:middle;">
     <td style="text-align: center; vertical-align: middle; border: solid 1px #cccccc;"><i>Arduino IDE with Output</i></td>
    </tr>
  </table>
</div>

!!! note
    There is also an example for Diligent's chipKIT Max32! For users that are interested in using the board, the example code is in the **chipkit** folder.

### Run the "MagTile Processing Visualization" Processing Example

Once this sketch is uploaded and a mode has been selected, we need to tell Processing how to turn this data into a visualization. The Processing sketch to do this is located one folder above the Arduino sketch: ... **SparkFun_Magnetic_Imaging_Tile** > **Software** > **Processing** > **magtile_processing_visualization** > **magtile_processing_visualization.pde**. Open the **magtile_processing_visualization.pde** file in Processing.

You can also copy and paste the following code in the Processing IDE as well.

``` c++
// Magnetic Imager Tile v3 Processing Visualization
// This code is intended to pair with the Arduino/Chipkit code for reading data
// from the magnetic imager tile v3, and streaming it through a Serial port.
//
// Two 8x8 grids are shown: a normal gain (top) and high-gain (bottom).  The
// high-gain is particularly useful for low-intensity fields.
//
// Keys (lower-case):
//   L  - Live mode.  Press this to start streaming data live from the tile.
//  1-4 - High-speed capture.  Capture a number of high-speed frames (set in
//        the Chipkit code) from the tile, and stream them back.  Note that
//        the actual framerate will depend upon the code/platform/ADC.  The
//        values displayed here (1 ~= ~2000Hz, 4 ~= 250Hz) are calibrated
//        from my Chipkit MAX32 platform, and may vary quite a bit if you're
//        using a different platform or code.
//   C  - When in LIVE mode, it's possible to press 'C' and calibrate out
//        the background level for each tile, to reduce the noise.  If you
//        do this, ensure that no fields are present on the tile.  
//        Alternatively: If a static field is present on the tile, this
//        will help show changes to that static field.
//
// Serial port: The serial port index is hard-coded in, and you will likel
//  have to change this for your platform.  See the //## comment marker in
//  the setup() function.
//

import processing.serial.*;

// Serial port vairables.
Serial myPort;  // Create object from Serial class
int val;        // Temporary variable storing data received from the serial port

// Array of x/y coordinates recieved over serial port.  Maximum number of recordings to store is MAX_RECORDINGS.
int MAX_SIZE = 8;
int[][] data = new int[MAX_SIZE][MAX_SIZE];
int curDataIdx = 0;      // Index of array element that has highest populated value (-1)

// Font (for drawing text)
PFont fontA;

// Screenshot index (for taking screenshots).
int screenshot_number = 0;

int numCalibFrames = 0;
int maxCalibFrames = 200;
int calibrationEnabled = 0;
int[][] dataCalib = new int[MAX_SIZE][MAX_SIZE];
int isCalibrated = 0;

String curText = "text";

// Called whenever there is serial data available to read
void serialEvent(Serial port) {
  // Data from the Serial port is read in serialEvent() using the readStringUntil() function with * as the end character.
  String input = port.readStringUntil(char(10));

  if (input != null) {
    // Helpful debug message: Uncomment to print message received   
    println( "Receiving:" + input);
    input = input.trim();    
    int split_point = input.indexOf(' ');
    if (split_point <= 0) {
      curDataIdx = 0;
      return;        // If data does not contain a comma, then disregard it.
    } else {
      // Parse data
      // The data is split into an array of Strings with a comma or asterisk as a delimiter and converted into an array of integers.
      float[] vals = float(splitTokens(input, " "));      
      if (vals.length != MAX_SIZE) return;

      // Store data      
      for (int i=0; i<MAX_SIZE; i++) {
        data[curDataIdx][i] = int(vals[i]);

        if (calibrationEnabled == 1) {
          dataCalib[curDataIdx][i] += int(vals[i]);                    
        }
      }

      // Increment index that we store new data at.      
      curDataIdx += 1;
      if (curDataIdx >= MAX_SIZE) {
        curDataIdx = 0;

        if (calibrationEnabled == 1) {
          numCalibFrames += 1;

          if (numCalibFrames > maxCalibFrames) {
            calibrationEnabled = 0;
            calibration();
          }
        }
      }

      // Helpful debug message: Display serial data after parsing.
      //println ("Parsed x:" + x + "  y:" + y);
    }
  }

  /*
      // Mask
    for (int i=0; i<12; i++) {
      for (int j=0; j<12; j++) {
        if ((i >= 2) && (i<= 7) && (j >= 2) && (j <= 9)) {
          if (j == 9) {
            data[i][j] = 400 - data[i][j];
          }
          // keep existing data
        } else {
          data[i][j] = 200;
        }
      }
    }
  */

}

void calibration() {

  println("Calibration Data:");
  for (int i=0; i<MAX_SIZE; i++) {
    for (int j=0; j<MAX_SIZE; j++) {
      dataCalib[i][j] = floor((float)dataCalib[i][j] / (float)maxCalibFrames);
      print (dataCalib[i][j] + "  ");      
    }
    println("");
  }

  isCalibrated = 1;
  curText = "";

}

// Draws a shape at each x/y location sent over the serial port.
// Only draws the last N locations, where N is equal to MAX_RECORDINGS (i.e. the size of the data array).
void draw_stored_data() {
    int pixelsize = 30;                // Size of shape to draw

    int offset_x = 10;
    int offset_y = 10;

    float MAX_VALUE_CALIB = 330.0f;  // Chipkit internal ADC
    float MAX_VALUE = 660.0f;        // Chipkit internal ADC

    //float MAX_VALUE = 400.0f;  // internal ADC
    //float MAX_VALUE = 7000.0f; // 14-bit external ADC

    for (int i=0; i<MAX_SIZE; i++) {
      for (int j=0; j<MAX_SIZE; j++) {
        int y = (MAX_SIZE-i) * pixelsize;
        int x = (MAX_SIZE-j) * pixelsize;

        if (isCalibrated == 1) {        
          //float value = (float)data[i][j] / MAX_VALUE;
          float value = ((float)data[i][j] - (float)dataCalib[i][j])/ MAX_VALUE;

          //float intensity = int(floor(255 * abs(value - 0.50f)));
          float intensity = int(255 * value);
          if (value < 0.0) {
            fill(-intensity, 0, 0);
            //stroke(value);
          } else {
            fill(0, intensity, 0);
            //stroke(value);
          }

        } else {
          float value = (float)data[i][j] / MAX_VALUE;          

          float intensity = int(floor(255 * abs(value - 0.50f)));
          if (value < 0.50) {
            fill(intensity, 0, 0);
            //stroke(value);
          } else {
            fill(0, intensity, 0);
            //stroke(value);
          }

        }
        rect(x + offset_x, y + offset_y, pixelsize, pixelsize);
      }
    }

    // Higher sensitivity
    offset_y = 450;
    for (int i=0; i<MAX_SIZE; i++) {
      for (int j=0; j<MAX_SIZE; j++) {
        int y = (MAX_SIZE-i) * pixelsize;
        int x = (MAX_SIZE-j) * pixelsize;

        if (isCalibrated == 1) {               
          float value = ((float)data[i][j] - (float)dataCalib[i][j])/ MAX_VALUE;

          float intensity = int(3000 * value);

          if (value < 0.0) {
            fill(-intensity, 0, 0);
            //stroke(value);
          } else {
            fill(0, intensity, 0);
            //stroke(value);
          }

        } else {
        float value = (float)data[i][j] / MAX_VALUE;                

        float intensity = int(floor(3000 * abs(value - 0.50f)));        

        if (value < 0.50) {
          fill(intensity, 0, 0);
          //stroke(value);
        } else {
          fill(0, intensity, 0);
          //stroke(value);
        }

        }
        rect(x + offset_x, y + offset_y, pixelsize, pixelsize);
      }
    }

}

// This function runs a single time after the program beings.
void setup() {
  size(600, 800);                    // Window size
  //colorMode(HSB, 255, 255, 255);     // Colour space

  // Initialize Serial Port
  println ("Available Serial Ports:");
  println (Serial.list());                     // Display a list of ports for the user.  
  String portName = Serial.list()[1];          //## Change the index (e.g. 1) to the index of the serial port that the
                                               // Arduino is connected to.
  print ("Using port: ");                      // Display the port that we are using.
  println(portName);
  println("This can be changed in the setup() function.");
  myPort = new Serial(this, portName, 115200);   // Open the serial port. (note, the baud rate (e.g. 9600) must match
                                               // the baud rate that the Arduino is transmitting at).

  // Initialize font
  fontA = createFont("Arial-black", 20);
  textFont(fontA, 20);

  // Initialize data array  (set all elements to zero).
  for (int i=0; i<MAX_SIZE; i++) {
    for (int j=0; j<MAX_SIZE; j++) {
      data[i][j] = 250;
    }
  }  

  // Send command

}

// This function runs repeatedly, like the loop() function in the Arduino language.
void draw() {

  background(255, 255, 255);             // Set background to white

  // At each iteration, draw the data currently specified in the 'data' array to the screen.    
  draw_stored_data();

  // Note: Serial data is updated in the background using the serialEvent() function above, so we don't
  // have to explicitly look for it (or parse it here).

  textAlign(CENTER);
  fill(0);
  text(curText, 150, 400);

}

// This is another interrupt function that runs whenever a key is pressed.
// Here, as an example, if the space key (' ') is pressed, then the program will save a screenshot.
// If the 'a' key is pressed, then the program will clear the data history.
void keyPressed() {
  // Press <space>: Save screenshot to file.
  if (key == ' ') {
   saveFrame("screenshot-" + screenshot_number + ".png");
   screenshot_number += 1;
  }

  // Press 'a': Clear data array
  if (key == 'a') {  
    for (int i=0; i<MAX_SIZE; i++) {
      for (int j=0; j<MAX_SIZE; j++) {
        data[i][j] = 0;
      }
    }  
    curDataIdx = 0;
  }  

  if (key == 'l') {
    myPort.write('L');
    myPort.write('\n');
    curText = "Live Feed";
  }
  if (key == 'h') {
    myPort.write('H');
    myPort.write('\n');    
  }
  if (key == 's') {
    myPort.write('S');
    myPort.write('\n');
    curText = "Idle";
  }

  if (key == '1') {
    myPort.write('1');
    myPort.write('\n');
    curText = "2000Hz capture";
  }
  if (key == '2') {
    myPort.write('2');
    myPort.write('\n');
    curText = "1000Hz capture";
  }
  if (key == '3') {
    myPort.write('3');
    myPort.write('\n');
    curText = "500Hz capture";
  }
  if (key == '4') {
    myPort.write('4');
    myPort.write('\n');
    curText = "250Hz capture";    
  }

  if (key == 'c') {
    for (int i=0; i<MAX_SIZE; i++) {
      for (int j=0; j<MAX_SIZE; j++) {
        dataCalib[i][j] = 0;      
      }
    }
    numCalibFrames = 0;
    calibrationEnabled = 1;
    curText = "Calibrating";
  }

  if (key == 'd') {
    println("Calibration Data:");
    for (int i=0; i<MAX_SIZE; i++) {
      for (int j=0; j<MAX_SIZE; j++) {      
        print (dataCalib[i][j] + "  ");      
      }
      println("");
    }
  }

}
```

Attempting to run the Processing sketch will show us available serial ports in the debug window from this line of code, where `portName` is defined as a string:

```bash
myPort = new Serial(this, portName, 115200);
```

Identify which serial port your Arduino is on. For instance, my SparkFun RedBoard Turbo is on COM10, which corresponds to the 8th element in the array as `[7]`. So I will need to change `1` to `7` where `portName` is defined to ensure that Processing is listening to the correct serial port.

<div style="text-align: center;">
  <table>
    <tr style="vertical-align:middle;">
     <td style="text-align: center; vertical-align: middle; border: solid 1px #cccccc;"><a href="../assets/img/Processing_COM_Port_Select.JPG">Adjusting Processing Example's Serial Port</a></td>
    </tr>
    <tr style="vertical-align:middle;">
     <td style="text-align: center; vertical-align: middle; border: solid 1px #cccccc;"><i>Adjusting Processing Example's Serial Port</i></td>
    </tr>   
  </table>
</div>

Once we've done this, we should be able to run the Processing sketch and it will give us a nice visualization of the magnetic fields in range of the Magnetic Imaging Tile. Send a character to set the mode. By sending a lower case <kbd>l</kbd> in the window with the visualization will set it to live mode and begin streaming data live from the tile. As explained in the example code, the top 8x8 grid will display the normal gain. The bottom 8x8 grid will display a high gain. Place a magnet near the array of hall effect sensors. In this case, a magnet was placed over (0,0) as shown in the Processing Console's serial output. The grid in this case did not show any changes.

<div style="text-align: center;">
  <table>
    <tr style="vertical-align:middle;">
     <td style="text-align: center; vertical-align: middle; border: solid 1px #cccccc;"><a href="../assets/img/Processing_0x_0y.JPG">Processing Output, Magnet Over (0,0)</a></td>
    </tr>
    <tr style="vertical-align:middle;">
     <td style="text-align: center; vertical-align: middle; border: solid 1px #cccccc;"><i>Processing Output, Magnet Over (0,0)</i></td>
    </tr>   
  </table>
</div>

Rotating the magnet to the other pole and place it over (0,0) again. In this case, the change was more apparent as we are able to view the magnetic fields in red. If you know the polarity of the magnet as explained earlier in the Arduino example, you will notice that the squares that have a red color are lower in magnitude whenever the magnet's north pole is placed over the hall effect sensor.

<div style="text-align: center;">
  <table>
    <tr style="vertical-align:middle;">
     <td style="text-align: center; vertical-align: middle; border: solid 1px #cccccc;"><a href="../assets/img/Processing_0x_0y_North.JPG">Processing Output, Magnet North Over (0,0)</a></td>
    </tr>
    <tr style="vertical-align:middle;">
     <td style="text-align: center; vertical-align: middle; border: solid 1px #cccccc;"><i>Processing Output, Magnet North Over (0,0)</i></td>
    </tr>   
  </table>
</div>

Rotating the magnet back to the other pole and place it to a different position near the array of hall effect sensors. In this case, the magnet was placed around (7,7) and did not show as much of a change in the 8x8 grid.

<div style="text-align: center;">
  <table>
    <tr style="vertical-align:middle;">
     <td style="text-align: center; vertical-align: middle; border: solid 1px #cccccc;"><a href="../assets/img/Processing_7x_7y.JPG">Processing Output, Magnet Over (7,7)</a></td>
    </tr>
    <tr style="vertical-align:middle;">
     <td style="text-align: center; vertical-align: middle; border: solid 1px #cccccc;"><i>Processing Output, Magnet Over (7,7)</i></td>
    </tr>   
  </table>
</div>

Rotate the magnet to the other pole and place it around (7,7). In this case, we are able to view the magnetic fields in red again.

<div style="text-align: center;">
  <table>
    <tr style="vertical-align:middle;">
     <td style="text-align: center; vertical-align: middle; border: solid 1px #cccccc;"><a href="../assets/img/Processing_7x_7y_North.JPG">Processing Output, Magnet North Over (7,7)</a></td>
    </tr>
    <tr style="vertical-align:middle;">
     <td style="text-align: center; vertical-align: middle; border: solid 1px #cccccc;"><i>Processing Output, Magnet North Over (7,7)</i></td>
    </tr>   
  </table>
</div>

When in live mode, it's also possible to calibrate out the background level for each tile to reduce the noise in the Processing example. Send a lower case <kbd>c</kbd> in the window with the visualization. When calibrating, ensure that there are no magnetic fields present around the tile. After a few seconds, the visualization will show a different color in the 8x8 grid.

<div style="text-align: center;">
  <table>
    <tr style="vertical-align:middle;">
     <td style="text-align: center; vertical-align: middle; border: solid 1px #cccccc;"><a href="../assets/img/Processing_Calibrated.JPG">Processing Output, Calibrated</a></td>
    </tr>
    <tr style="vertical-align:middle;">
     <td style="text-align: center; vertical-align: middle; border: solid 1px #cccccc;"><i>Processing Output, Calibrated</i></td>
    </tr>   
  </table>
</div>

Place a magnet over (0,0). In this case, the change was apparent with both sides of the magnet where the magnet's south pole was shown with green and the magnet's north pole was shown with red.

<div style="text-align: center;">
  <table>
    <tr style="vertical-align:middle;">
     <td style="text-align: center; vertical-align: middle; border: solid 1px #cccccc;"><a href="../assets/img/Processing_0x_0y_Calibrated.JPG">Processing Output, Calibrated with Magnet Over (0,0)</a></td>
     <td style="text-align: center; vertical-align: middle; border: solid 1px #cccccc;"><a href="../assets/img/Processing_0x_0y_North_Calibrated.JPG">Processing Output, Calibrated with Magnet North Over (0,0)</a></td>
    </tr>
    <tr style="vertical-align:middle;">
     <td style="text-align: center; vertical-align: middle; border: solid 1px #cccccc;"><i>Processing Output, Calibrated with Magnet Over (0,0)</i></td>
     <td style="text-align: center; vertical-align: middle; border: solid 1px #cccccc;"><i>Processing Output, Calibrated with Magnet North Over (0,0)</i></td>
    </tr>   
  </table>
</div>

Place the magnet over (7,7). You should see something similar like the images below. The color of the magnetic field in the grid will depend on the orientation of the magnet.

<div style="text-align: center;">
  <table>
    <tr style="vertical-align:middle;">
     <td style="text-align: center; vertical-align: middle; border: solid 1px #cccccc;"><a href="../assets/img/Processing_7x_7y_Calibrated.JPG">Processing Output, Calibrated with Magnet Over (7,7)</a></td>
     <td style="text-align: center; vertical-align: middle; border: solid 1px #cccccc;"><a href="../assets/img/Processing_7x_7y_North_Calibrated.JPG">Processing Output, Calibrated with Magnet North Over (7,7)</a></td>
    </tr>
    <tr style="vertical-align:middle;">
     <td style="text-align: center; vertical-align: middle; border: solid 1px #cccccc;"><i>Processing Output, Calibrated with Magnet Over (7,7)</i></td>
     <td style="text-align: center; vertical-align: middle; border: solid 1px #cccccc;"><i>Processing Output, Calibrated with Magnet North Over (7,7)</i></td>
    </tr>   
  </table>
</div>

Now that we can see the magnetic fields from a magnet, try grabbing an object nearby to see if you can view any magnetic fields!

<div style="text-align: center;">
  <table>
    <tr style="vertical-align:middle;">
     <td style="text-align: center; vertical-align: middle; border: solid 1px #cccccc;"><a href="../assets/img/26943_Magnetic_Imaging_Tile_Hall_Effect_Sensors_Neodymium_Magnets_Action.gif">Processing Output with a Magnet Moving over the Magnetic Imaging Tile</a></td>
     <td style="text-align: center; vertical-align: middle; border: solid 1px #cccccc;"><a href="../assets/img/26943_Magnetic_Imaging_Tile_Hall_Effect_Sensors_Magnets_FanAction.gif">Processing Output with a Fan Rotating over the Magnetic Imaging Tile</a></td>
    </tr>
    <tr style="vertical-align:middle;">
     <td style="text-align: center; vertical-align: middle; border: solid 1px #cccccc;"><i>Processing Output with a Magnet Moving<br />over the Magnetic Imaging Tile</i></td>
     <td style="text-align: center; vertical-align: middle; border: solid 1px #cccccc;"><i>Processing Output with a Fan Rotating<br />over the Magnetic Imaging Tile</i></td>
    </tr>   
  </table>
</div>

!!! note
    If you look closely at the GIF with a magnet, you will notice that there is a magnetic field on the upper left of the Processing output when the magnet is placed over the Magnetic Imaging Tile. However, the Magnetic Imaging Tile is rotated 90&deg; clockwise with respect to the Processing output as the magnet is placed over the hall effect sensor at (7x7).

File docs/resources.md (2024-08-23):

Now that you've successfully got your SparkFun Magnetic Imaging Tile up and running, it's time to incorporate it into your own project! For more information, check out the resources below:

* [Schematic (PDF)](../assets/board_files/Magnetic_Imaging_Tile_Schematic_V10.pdf)
* [Eagle Files (ZIP)](../assets/board_files/Magnetic-Imaging-Tile_v10.zip)
* [Board Dimensions (PNG)](../assets/img/SparkFun_Magnetic_Imaging_Tile_Board_Dimensions.png)
* Component Datasheets
    * [DRV5053 Analog-Bipolar Hall Effect Sensor](../assets/component_documentation/drv5053.pdf)
    * [AD7680 16-bit 100kSPS Successive Approximation ADC](../assets/component_documentation/AD7680.pdf)
    * [74HC590A Binary Counter](../assets/component_documentation/sn54hc590a.pdf)
    * [SN74LVC1G139DCTR 2-to-4 Line Decoder](../assets/component_documentation/sn74lvc1g139.pdf)
    * [CD74HC4067 12-Channel Analog/Digital Multiplexor](../assets/component_documentation/cd74hc4067.pdf)
* [Fritzing Part](https://github.com/sparkfun/Fritzing_Parts/blob/main/products/26092_sfe_magnetic_imaging_tile_8x8_hall_effect_sensor_drv5053va_adc_ad7680.fzpz)
* Examples
    * [ChipKit](https://github.com/sparkfun/SparkFun_Magnetic_Imaging_Tile/blob/main/Software/chipkit/magtile2d_chipkit.pde)
    * [Arduino](https://github.com/sparkfun/SparkFun_Magnetic_Imaging_Tile/blob/main/Software/arduino/Example1_BasicReadings/Example1_BasicReadings.ino)
    * [Processing](https://github.com/sparkfun/SparkFun_Magnetic_Imaging_Tile/blob/main/Software/processing/magtile_processing_visualization/magtile_processing_visualization.pde)
* [GitHub Hardware Repo](https://github.com/sparkfun/SparkFun_Magnetic_Imaging_Tile/)

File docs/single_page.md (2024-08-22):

---
hide:
  - navigation
  - toc
icon: fontawesome/solid/scroll
---

# Introduction
--8<-- "./docs/introduction.md"

# Hardware Overview
--8<-- "./docs/hardware_overview.md"

# Hardware Hookup
--8<-- "./docs/hardware_hookup.md"

# Setting Up Arduino
--8<-- "./docs/setting_up_arduino.md"

# Arduino Example
--8<-- "./docs/arduino_example.md"

# Setting Up Processing
--8<-- "./docs/setting_up_processing.md"

# Processing Example
--8<-- "./docs/processing_example.md"

# Troubleshooting
--8<-- "./docs/troubleshooting.md"

# Resources
--8<-- "./docs/resources.md"

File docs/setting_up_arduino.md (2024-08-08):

!!! arduino
    This example assumes you are using the latest version of the Arduino IDE on your desktop. If this is your first time using Arduino IDE, library, or board add-on, please review the following tutorials.

    - [Installing the Arduino IDE](https://learn.sparkfun.com/tutorials/installing-arduino-ide)
    - [Installing an Arduino Library](https://learn.sparkfun.com/tutorials/installing-an-arduino-library)
    - [Installing Board Definitions in the Arduino IDE](https://learn.sparkfun.com/tutorials/installing-board-definitions-in-the-arduino-ide)

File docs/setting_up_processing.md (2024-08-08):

Processing is a software that enables visual representation of data, among other things. If you've never dealt with Processing before, we recommend you also check out the [Arduino to Processing](https://learn.sparkfun.com/tutorials/connecting-arduino-to-processing) tutorial. Follow the below button to download and install Processing.

<div style="text-align: center"><a href="https://processing.org/download/" target="download_processing_ide" class="md-button">Download Processing IDE</a></div>

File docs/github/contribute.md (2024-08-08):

# Contribute: Help Fix our Mistake!
Spot something wrong? Feel free to contribute our open-source design and documentation. 

## Improve our Documentation
All of this documentation can be modified by you! Please help us make it better.

* These pages are contained in the [`docs` folder of the SparkFun Magnetic Imaging Tile repository](https://github.com/sparkfun/SparkFun_Magnetic_Imaging_Tile/tree/main/docs).

### Submit a Correction
1. Fork this repo
2. Add your corrections or improvements to the markdown file
3. File a pull request with your changes, and enjoy making the ~~words~~ ~~worlds~~ world a better place.
    * Once received, the documentation specialist will automatically be notified.
    * We will review your suggested improvements to make sure they are correct and fit within our documentation standards.

## Improve our Hardware Design
All of our designs are open-source! Please help us make it better.

* Our board design files are contained in the [`Hardware` folder of the SparkFun Magnetic Imaging Tile repository](https://github.com/sparkfun/SparkFun_Magnetic_Imaging_Tile/tree/main/Hardware).

### Submit a Design Improvement
1. Fork this repo
2. Add your design improvements
3. File a pull request with your changes, and enjoy making the ~~words~~ ~~worlds~~ world a better place.
    * Once received, the engineer in charge of the original design will automatically be notified.
    * We will review your suggested improvements, if they are within our board design standards and meet our product design requirements, we will flag these changes for our next board revision. *(Please note, that even if your suggestion is accepted, these changes may not be immediate. We may have to cycle through our current product inventory first.)*

## Contributors
Let's provided some recognition to the contributors for this project!

GitHub Contributors Image
<br>


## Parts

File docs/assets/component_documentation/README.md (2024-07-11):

SparkFun Documentation
=======================

This directory should include any necessary datasheets, example number crunching, etc.

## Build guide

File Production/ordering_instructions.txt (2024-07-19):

panel size, 119x188mm
PCB thickness, 1.6mm
number of layers, 2
soldermask color, Red
silkscreen color, White
oz copper, 1oz
finish, HASL lead free
stencils, top+bottom
pcs per panel, 10
min trace width, 0.1524mm / 0.0060in
min drill size, 0.3048mm / 0.0120in

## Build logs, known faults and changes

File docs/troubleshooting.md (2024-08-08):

### General Troubleshooting Help

!!! note
    <span class="glyphicon glyphicon-question-sign" aria-hidden="true"></span>
        <strong> Not working as expected and need help? </strong> <br /><br />

    If you need technical assistance and more information on a product that is not working as you expected, we recommend heading on over to the <a href="https://www.sparkfun.com/technical_assistance">SparkFun Technical Assistance</a> page for some initial troubleshooting. <br /><br />

    <div style="text-align: center"><a href="https://www.sparkfun.com/technical_assistance" target="sfe_technical_assistance" class="md-button">SparkFun Technical Assistance Page</a></div>

    If you don't find what you need there, the <a href="https://community.sparkfun.com/">SparkFun Forums</a> are a great place to find and ask for help. If this is your first visit, you'll need to create a forum account to search product forums and post questions.<br /><br />

    <div style="text-align: center"><a href="https://community.sparkfun.com/" class="md-button md-button--primary">Log Into SparkFun Forums</a></div>

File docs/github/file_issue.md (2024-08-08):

# Did we make a mistake?

Spot something wrong? Please let us know. 

!!! attention
    This is not where customers should seek assistance on a product. If you require technical assistance or have questions about a product that is not working as expected, please head over to the [SparkFun Technical Assistance](https://www.sparkfun.com/technical_assistance) page for some initial troubleshooting.
    <center>
    [SparkFun Technical Assistance Page](https://www.sparkfun.com/technical_assistance){ .md-button .md-button--primary }
    </center>

    If you can't find what you need there, you'll need a [Forum Account](https://forum.sparkfun.com/ucp.php?mode=register) to search product forums and post questions.

## Discrepancies in the Documentation

All of this documentation can be modified by you! Please help us make it better.

* The documentation files for these pages are contained in the [`docs` folder of the SparkFun Magnetic Imaging Tile repository](https://github.com/sparkfun/SparkFun_Magnetic_Imaging_Tile/tree/main/docs).

### Spot something wrong?
If a section of the documentation is incorrect, please [open an issue](https://github.com/sparkfun/SparkFun_Magnetic_Imaging_Tile/issues) and let us know.

### Do you have a suggested correction?
1. With a GitHub account, fork this repo
2. Add your correction(s) or improvement(s) to the markdown file(s)
3. File a pull request with your changes, and enjoy making the ~~words~~ ~~worlds~~ world a better place.
    * Once received, the documentation specialist will automatically be notified.
    * We will review your suggested improvement(s) to make sure they are correct and fit within our documentation standards.

## Problems in the Hardware Design

All of our designs are open-source! Please help us make it better.

* Our board design files are contained in the [`Hardware` folder of the SparkFun Magnetic Imaging Tile repository](https://github.com/sparkfun/SparkFun_Magnetic_Imaging_Tile/tree/main/Hardware).

### Does something not make sense?
If part of the design is confusing, please [open an issue](https://github.com/sparkfun/SparkFun_Magnetic_Imaging_Tile/issues) and let us know.

### Did we forget to include an important function of the board?
* Please keep in mind that we may intentionally exclude certain functions of the board to meet our product design requirements. *(For example, our Qwiic Micro boards are intended to fit on a small board layout and only use I<sup>2</sup>C communication; therefore, we may not have the SPI and interrupt pins available for users.)*
* If part of the board's functionality is missing, please [open an issue](https://github.com/sparkfun/SparkFun_Magnetic_Imaging_Tile/issues) and file a feature request.

### Do you wish to contribute directly to improving the board design?
1. With a GitHub account, Fork this repo
2. Add your design improvement(s)
3. File a pull request with your changes, and enjoy making the ~~words~~ ~~worlds~~ world a better place.
    * Once received, the engineer in charge of the original design will automatically be notified.
    * We will review your suggested improvement(s), if they are within our board design standards and meet our product design requirements, we will flag these changes for our next board revision. *(Please note, that even if your suggestion is accepted, these changes may not be immediate. We may have to cycle through our current product inventory first.)*

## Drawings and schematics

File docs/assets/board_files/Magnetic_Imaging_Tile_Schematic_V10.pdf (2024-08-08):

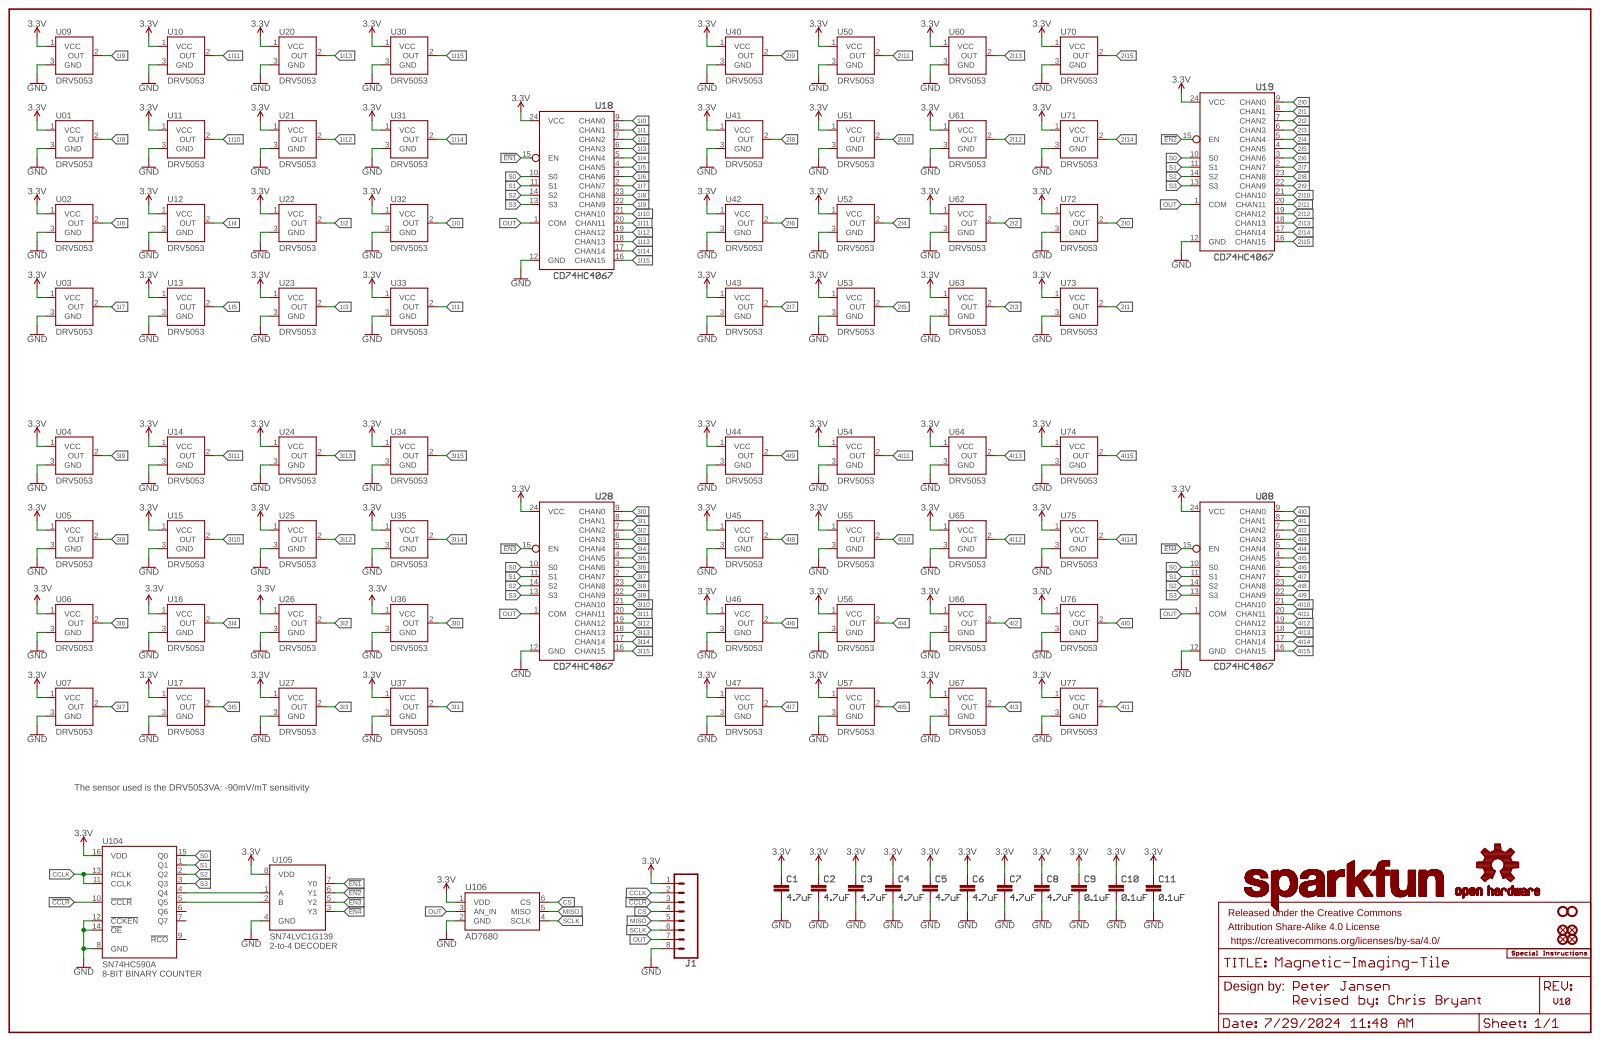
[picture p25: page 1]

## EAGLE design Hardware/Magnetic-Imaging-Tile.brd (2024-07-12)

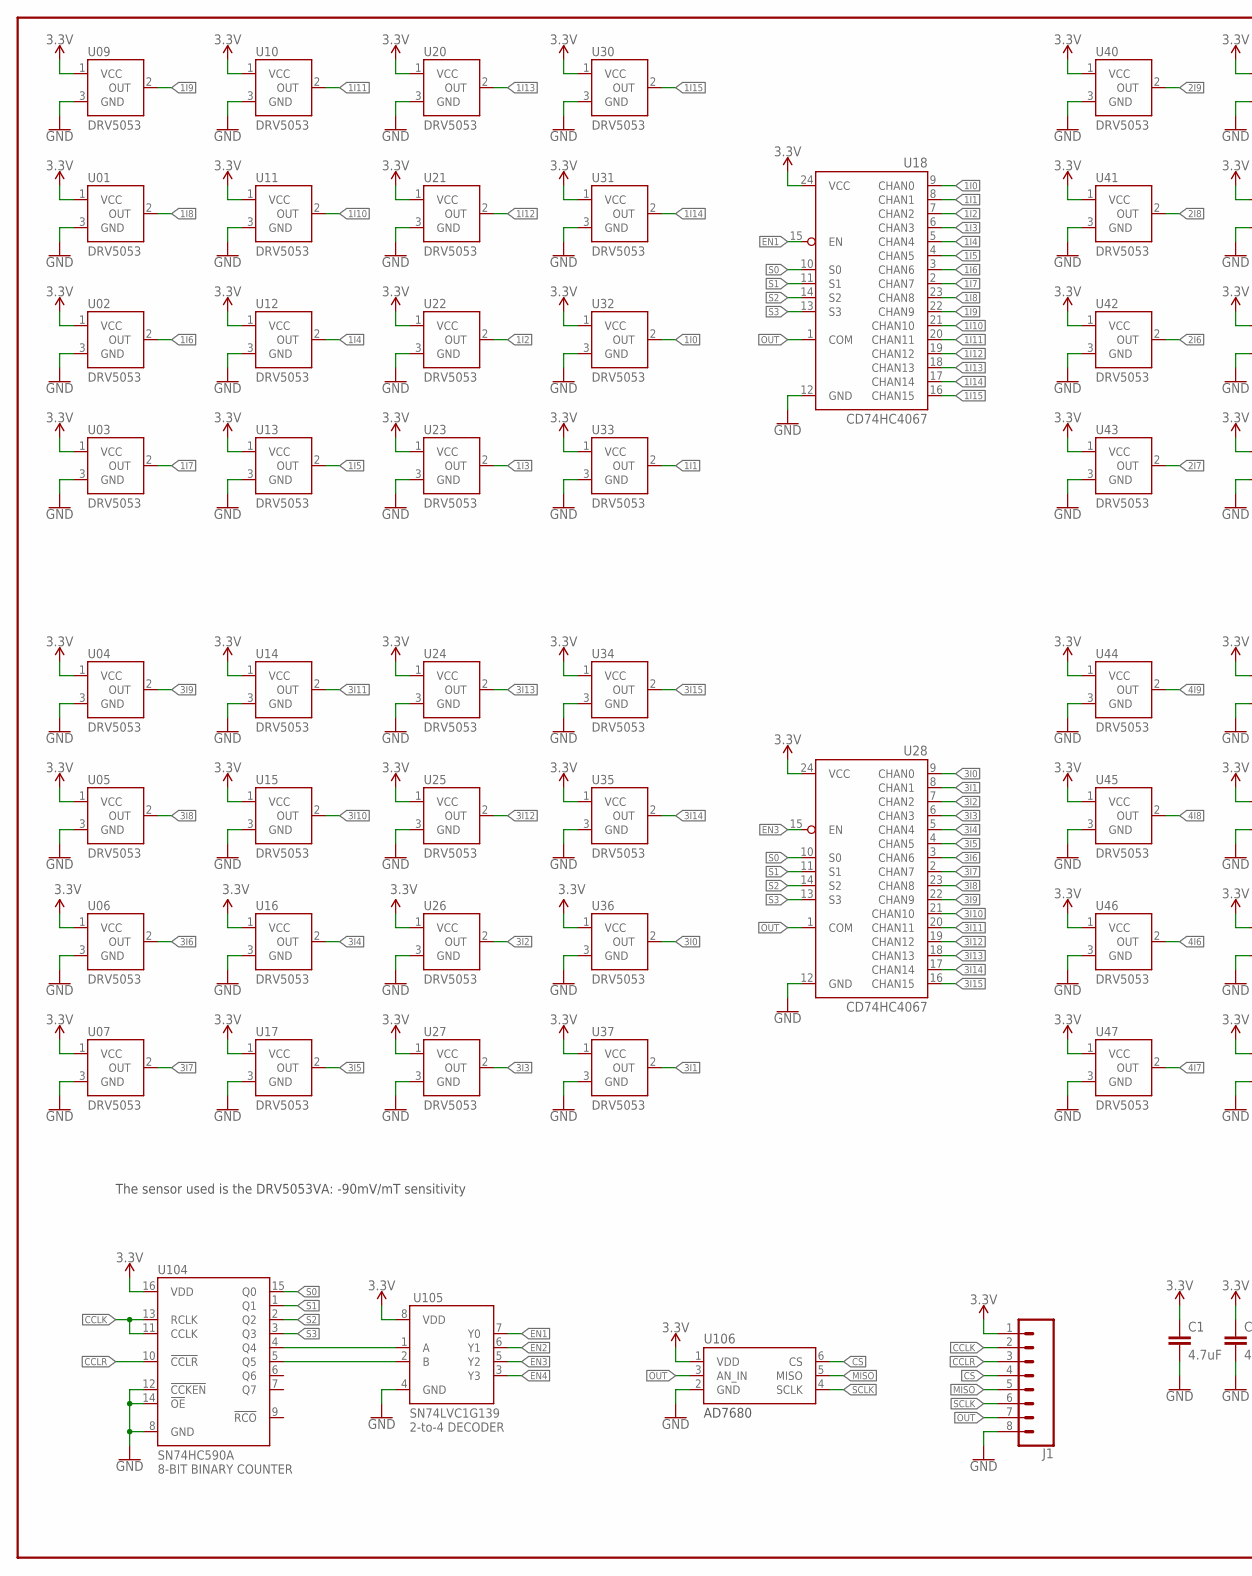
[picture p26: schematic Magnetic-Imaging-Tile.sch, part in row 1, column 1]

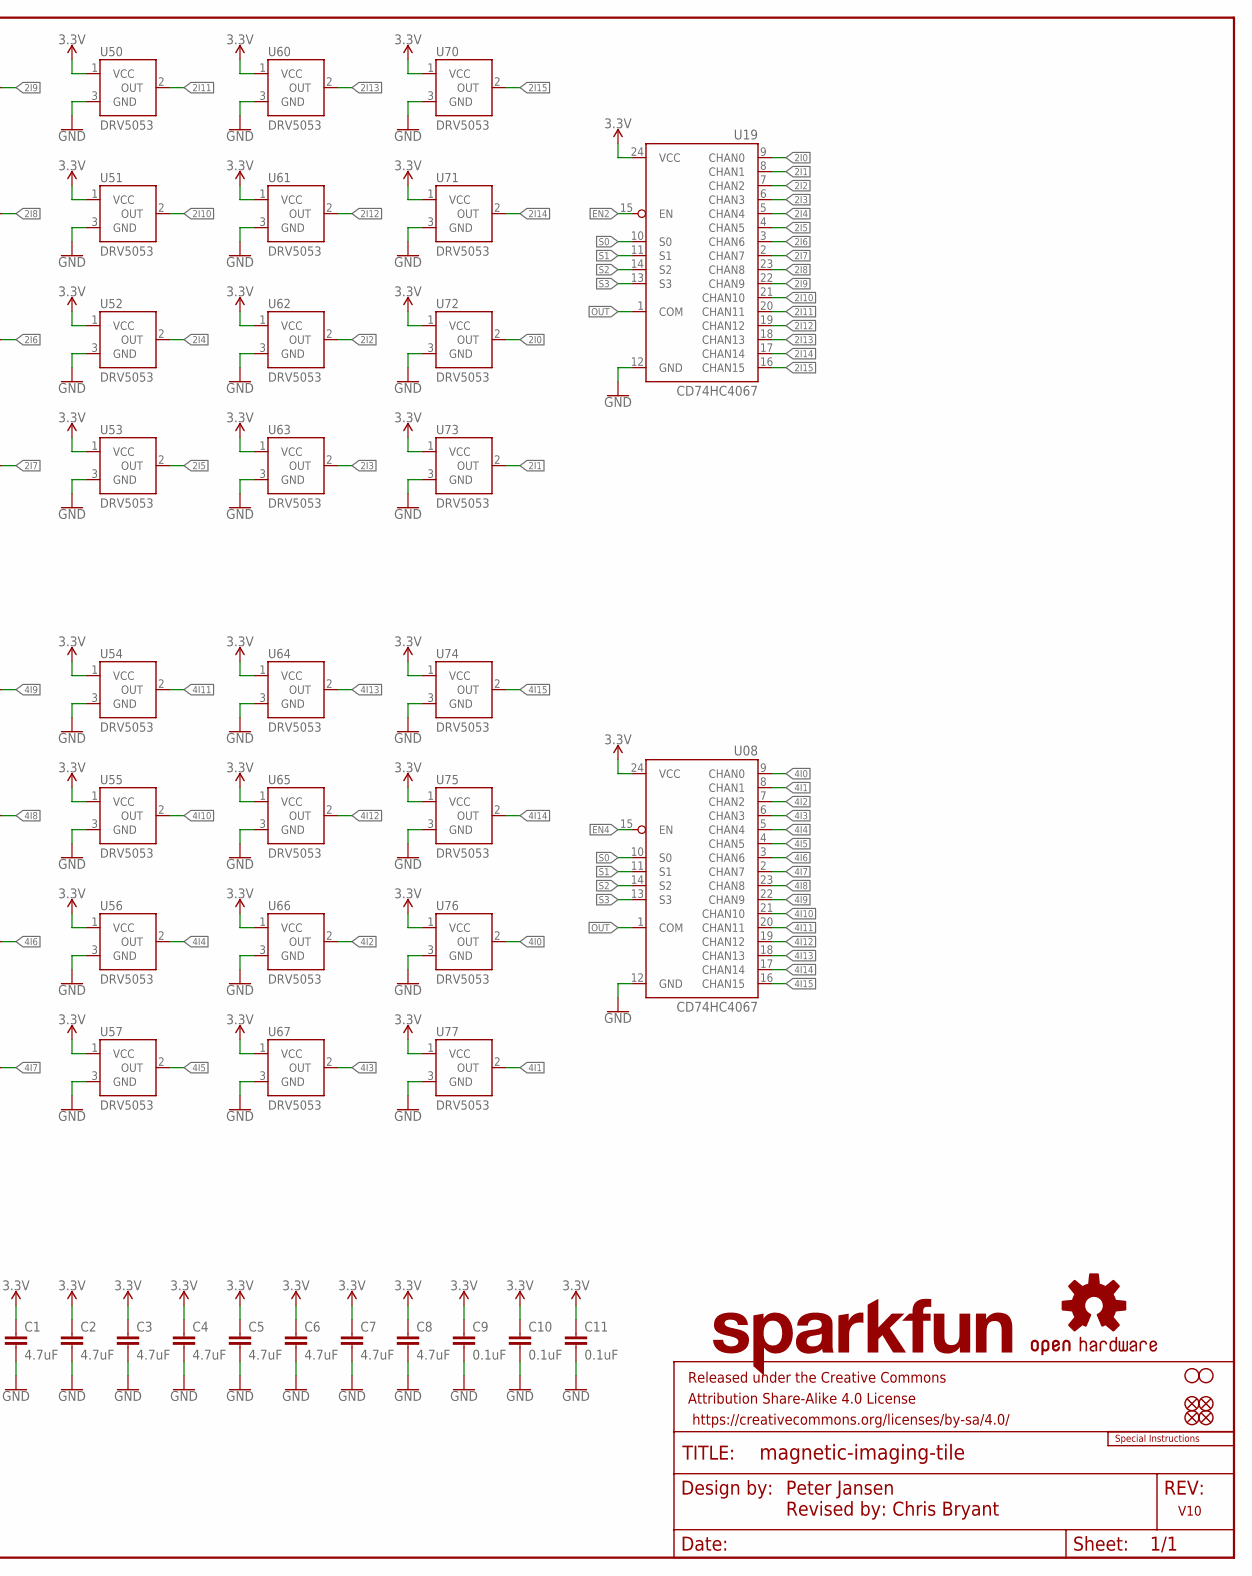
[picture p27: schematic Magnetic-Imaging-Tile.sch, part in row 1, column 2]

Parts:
C1, C2, C3, C4, C5, C6, C7, C8: 4.7uF; 0603
C9, C10, C11: 0.1uF; 0603
FD1, FD2, FD3, FD4: FIDUCIALUFIDUCIAL; FIDUCIAL-MICRO
FRAME1: FRAME-LEDGER; CREATIVE_COMMONS
H1, H2: STAND-OFF
J1: CONN_08LOCK_NO_SILK; 1X08_LOCK_NO_SILK
LOGO1: SPECIAL_INSTRUCTIONS-ORDERING; ORDERING_INSTRUCTIONS
LOGO3: SFE_LOGO_NAME.1_INCH; SFE_LOGO_NAME_.1
LOGO4: OSHW-LOGOS; OSHW-LOGO-S
U01, U02, U03, U04, U05, U06, U07, U09, U10, U11, U12, U13, U14, U15, U16, U17, U20, U21, U22, U23, U24, U25, U26, U27, U30, U31, U32, U33, U34, U35, U36, U37, U40, U41, U42, U43, U44, U45, U46, U47, U50, U51, U52, U53, U54, U55, U56, U57, U60, U61, U62, U63, U64, U65, U66, U67, U70, U71, U72, U73, U74, U75, U76, U77: DRV5053; SOT23-3
U08, U18, U19, U28: CD74HC4067; SSOP24
U104: SN74HC590A; SO16
U105: SN74LVC1G139; SM8
U106: AD7680; SOT23-6

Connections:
1I0: U18.9 (CHAN0), U32.2 (OUT)
1I1: U18.8 (CHAN1), U33.2 (OUT)
1I2: U18.7 (CHAN2), U22.2 (OUT)
1I3: U18.6 (CHAN3), U23.2 (OUT)
1I4: U12.2 (OUT), U18.5 (CHAN4)
1I5: U13.2 (OUT), U18.4 (CHAN5)
1I6: U02.2 (OUT), U18.3 (CHAN6)
1I7: U03.2 (OUT), U18.2 (CHAN7)
1I8: U01.2 (OUT), U18.23 (CHAN8)
1I9: U09.2 (OUT), U18.22 (CHAN9)
1I10: U11.2 (OUT), U18.21 (CHAN10)
1I11: U10.2 (OUT), U18.20 (CHAN11)
1I12: U18.19 (CHAN12), U21.2 (OUT)
1I13: U18.18 (CHAN13), U20.2 (OUT)
1I14: U18.17 (CHAN14), U31.2 (OUT)
1I15: U18.16 (CHAN15), U30.2 (OUT)
2I0: U19.9 (CHAN0), U72.2 (OUT)
2I1: U19.8 (CHAN1), U73.2 (OUT)
2I2: U19.7 (CHAN2), U62.2 (OUT)
2I3: U19.6 (CHAN3), U63.2 (OUT)
2I4: U19.5 (CHAN4), U52.2 (OUT)
2I5: U19.4 (CHAN5), U53.2 (OUT)
2I6: U19.3 (CHAN6), U42.2 (OUT)
2I7: U19.2 (CHAN7), U43.2 (OUT)
2I8: U19.23 (CHAN8), U41.2 (OUT)
2I9: U19.22 (CHAN9), U40.2 (OUT)
2I10: U19.21 (CHAN10), U51.2 (OUT)
2I11: U19.20 (CHAN11), U50.2 (OUT)
2I12: U19.19 (CHAN12), U61.2 (OUT)
2I13: U19.18 (CHAN13), U60.2 (OUT)
2I14: U19.17 (CHAN14), U71.2 (OUT)
2I15: U19.16 (CHAN15), U70.2 (OUT)
3.3V: C1.1, C2.1, C3.1, C4.1, C5.1, C6.1, C7.1, C8.1, C9.1, C10.1, C11.1, J1.1, U01.1 (VCC), U02.1 (VCC), U03.1 (VCC), U04.1 (VCC), U05.1 (VCC), U06.1 (VCC), U07.1 (VCC), U08.24 (VCC), U09.1 (VCC), U10.1 (VCC), U11.1 (VCC), U12.1 (VCC), U13.1 (VCC), U14.1 (VCC), U15.1 (VCC), U16.1 (VCC), U17.1 (VCC), U18.24 (VCC), U19.24 (VCC), U20.1 (VCC), U21.1 (VCC), U22.1 (VCC), U23.1 (VCC), U24.1 (VCC), U25.1 (VCC), U26.1 (VCC), U27.1 (VCC), U28.24 (VCC), U30.1 (VCC), U31.1 (VCC), U32.1 (VCC), U33.1 (VCC), U34.1 (VCC), U35.1 (VCC), U36.1 (VCC), U37.1 (VCC), U40.1 (VCC), U41.1 (VCC), U42.1 (VCC), U43.1 (VCC), U44.1 (VCC), U45.1 (VCC), U46.1 (VCC), U47.1 (VCC), U50.1 (VCC), U51.1 (VCC), U52.1 (VCC), U53.1 (VCC), U54.1 (VCC), U55.1 (VCC), U56.1 (VCC), U57.1 (VCC), U60.1 (VCC), U61.1 (VCC), U62.1 (VCC), U63.1 (VCC), U64.1 (VCC), U65.1 (VCC), U66.1 (VCC), U67.1 (VCC), U70.1 (VCC), U71.1 (VCC), U72.1 (VCC), U73.1 (VCC), U74.1 (VCC), U75.1 (VCC), U76.1 (VCC), U77.1 (VCC), U104.16 (VDD), U105.8 (VDD), U106.1 (VDD)
3I0: U28.9 (CHAN0), U36.2 (OUT)
3I1: U28.8 (CHAN1), U37.2 (OUT)
3I2: U26.2 (OUT), U28.7 (CHAN2)
3I3: U27.2 (OUT), U28.6 (CHAN3)
3I4: U16.2 (OUT), U28.5 (CHAN4)
3I5: U17.2 (OUT), U28.4 (CHAN5)
3I6: U06.2 (OUT), U28.3 (CHAN6)
3I7: U07.2 (OUT), U28.2 (CHAN7)
3I8: U05.2 (OUT), U28.23 (CHAN8)
3I9: U04.2 (OUT), U28.22 (CHAN9)
3I10: U15.2 (OUT), U28.21 (CHAN10)
3I11: U14.2 (OUT), U28.20 (CHAN11)
3I12: U25.2 (OUT), U28.19 (CHAN12)
3I13: U24.2 (OUT), U28.18 (CHAN13)
3I14: U28.17 (CHAN14), U35.2 (OUT)
3I15: U28.16 (CHAN15), U34.2 (OUT)
4I0: U08.9 (CHAN0), U76.2 (OUT)
4I1: U08.8 (CHAN1), U77.2 (OUT)
4I2: U08.7 (CHAN2), U66.2 (OUT)
4I3: U08.6 (CHAN3), U67.2 (OUT)
4I4: U08.5 (CHAN4), U56.2 (OUT)
4I5: U08.4 (CHAN5), U57.2 (OUT)
4I6: U08.3 (CHAN6), U46.2 (OUT)
4I7: U08.2 (CHAN7), U47.2 (OUT)
4I8: U08.23 (CHAN8), U45.2 (OUT)
4I9: U08.22 (CHAN9), U44.2 (OUT)
4I10: U08.21 (CHAN10), U55.2 (OUT)
4I11: U08.20 (CHAN11), U54.2 (OUT)
4I12: U08.19 (CHAN12), U65.2 (OUT)
4I13: U08.18 (CHAN13), U64.2 (OUT)
4I14: U08.17 (CHAN14), U75.2 (OUT)
4I15: U08.16 (CHAN15), U74.2 (OUT)
!CCLR: J1.3, U104.10 (!CCLR)
!EN1: U18.15 (EN), U105.7 (Y0)
!EN2: U19.15 (EN), U105.6 (Y1)
!EN3: U28.15 (EN), U105.5 (Y2)
!EN4: U08.15 (EN), U105.3 (Y3)
CCLK: J1.2, U104.11 (CCLK), U104.13 (RCLK)
CS: J1.4, U106.6 (CS)
GND: C1.2, C2.2, C3.2, C4.2, C5.2, C6.2, C7.2, C8.2, C9.2, C10.2, C11.2, J1.8, U01.3 (GND), U02.3 (GND), U03.3 (GND), U04.3 (GND), U05.3 (GND), U06.3 (GND), U07.3 (GND), U08.12 (GND), U09.3 (GND), U10.3 (GND), U11.3 (GND), U12.3 (GND), U13.3 (GND), U14.3 (GND), U15.3 (GND), U16.3 (GND), U17.3 (GND), U18.12 (GND), U19.12 (GND), U20.3 (GND), U21.3 (GND), U22.3 (GND), U23.3 (GND), U24.3 (GND), U25.3 (GND), U26.3 (GND), U27.3 (GND), U28.12 (GND), U30.3 (GND), U31.3 (GND), U32.3 (GND), U33.3 (GND), U34.3 (GND), U35.3 (GND), U36.3 (GND), U37.3 (GND), U40.3 (GND), U41.3 (GND), U42.3 (GND), U43.3 (GND), U44.3 (GND), U45.3 (GND), U46.3 (GND), U47.3 (GND), U50.3 (GND), U51.3 (GND), U52.3 (GND), U53.3 (GND), U54.3 (GND), U55.3 (GND), U56.3 (GND), U57.3 (GND), U60.3 (GND), U61.3 (GND), U62.3 (GND), U63.3 (GND), U64.3 (GND), U65.3 (GND), U66.3 (GND), U67.3 (GND), U70.3 (GND), U71.3 (GND), U72.3 (GND), U73.3 (GND), U74.3 (GND), U75.3 (GND), U76.3 (GND), U77.3 (GND), U104.8 (GND), U104.12 (!CCKEN), U104.14 (!OE), U105.4 (GND), U106.2 (GND)
MISO: J1.5, U106.5 (MISO)
unnamed: U104.4 (Q4), U105.1 (A)
unnamed: U104.5 (Q5), U105.2 (B)
OUT: J1.7, U08.1 (COM), U18.1 (COM), U19.1 (COM), U28.1 (COM), U106.3 (AN_IN)
S0: U08.10 (S0), U18.10 (S0), U19.10 (S0), U28.10 (S0), U104.15 (Q0)
S1: U08.11 (S1), U18.11 (S1), U19.11 (S1), U28.11 (S1), U104.1 (Q1)
S2: U08.14 (S2), U18.14 (S2), U19.14 (S2), U28.14 (S2), U104.2 (Q2)
S3: U08.13 (S3), U18.13 (S3), U19.13 (S3), U28.13 (S3), U104.3 (Q3)
SCLK: J1.6, U106.4 (SCLK)

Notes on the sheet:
The sensor used is the DRV5053VA: -90mV/mT sensitivity
Peter Jansen Revised by: Chris Bryant
V10

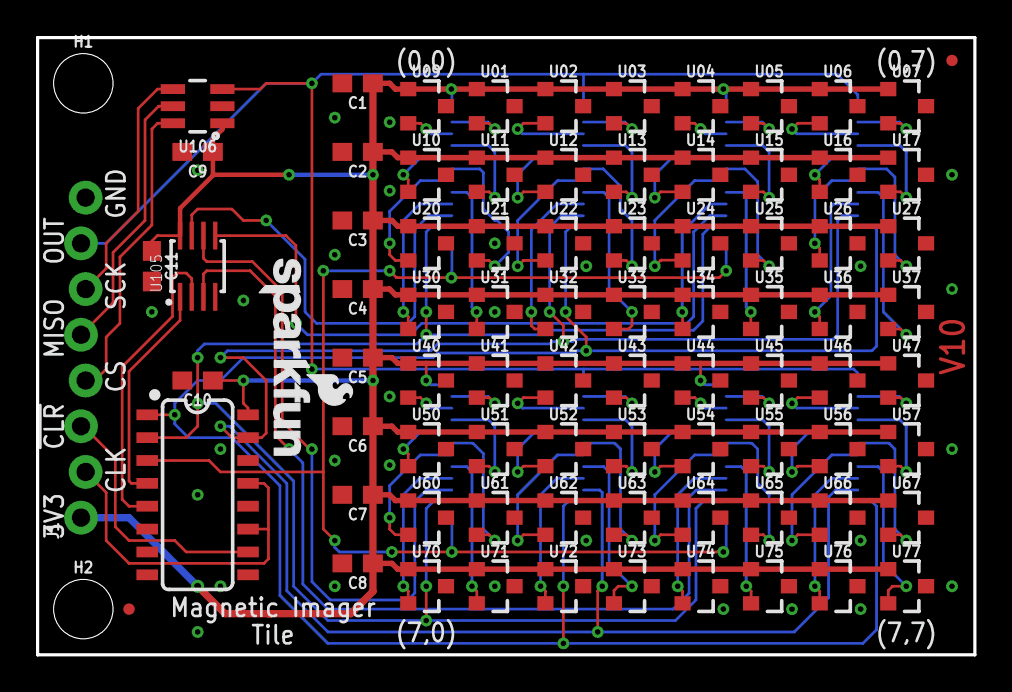
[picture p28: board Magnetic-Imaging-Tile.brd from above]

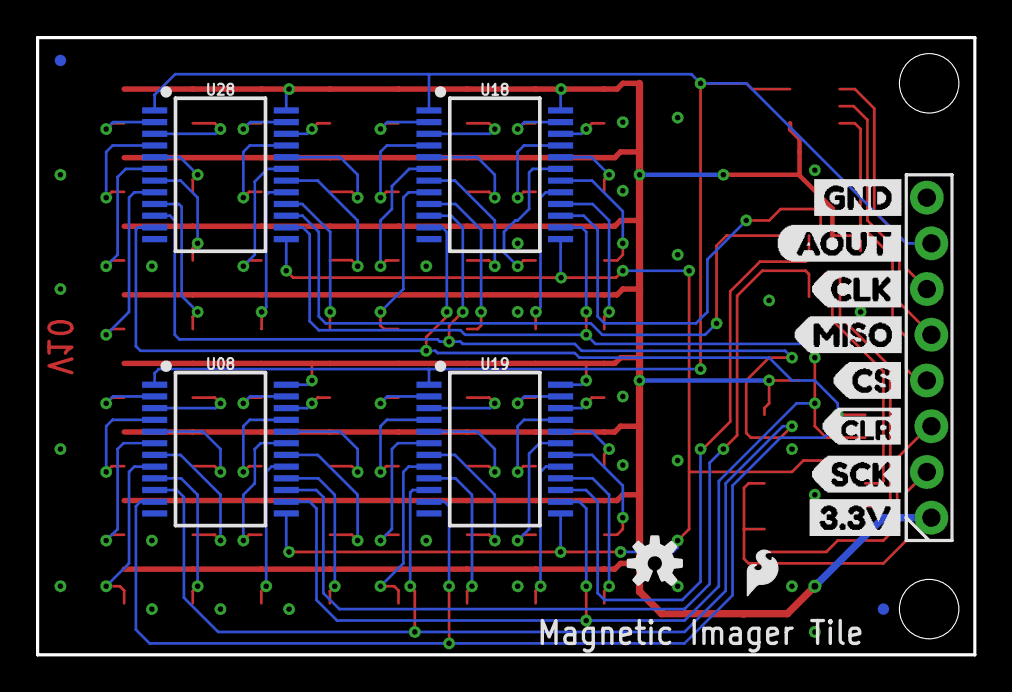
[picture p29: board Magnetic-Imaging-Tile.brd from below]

Board: 2 copper layers, 52.1 x 34.3 mm, 103 parts (16 on the bottom side), 82 nets.

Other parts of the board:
U$1, U$2: SFE_LOGO_FLAME_.1
U$3: GND
U$4: #CLR
U$5: 3#3V
U$6: AOUT
U$7: CLK
U$8: MISO
U$9: SCK
U$10: CS

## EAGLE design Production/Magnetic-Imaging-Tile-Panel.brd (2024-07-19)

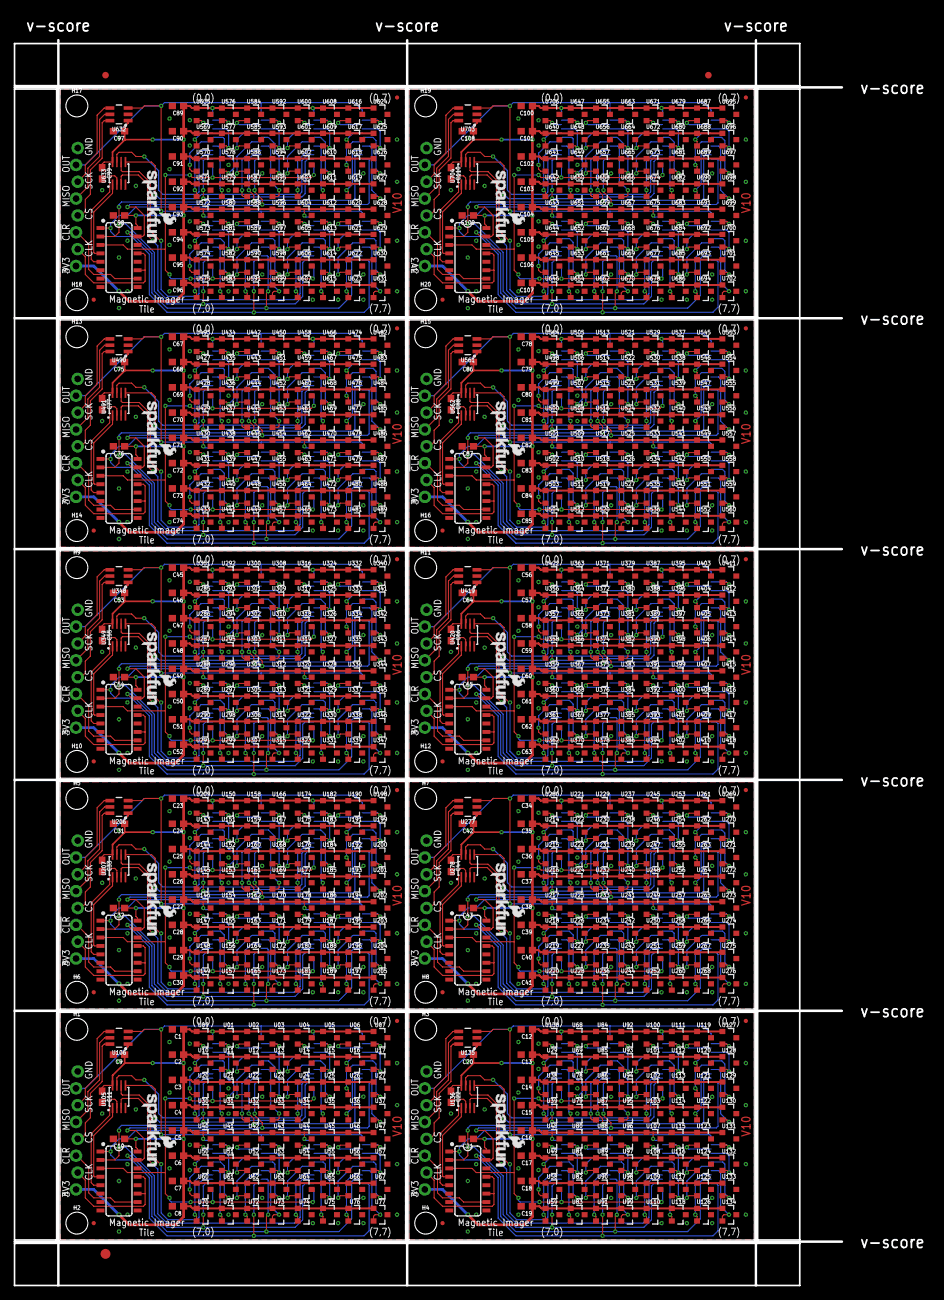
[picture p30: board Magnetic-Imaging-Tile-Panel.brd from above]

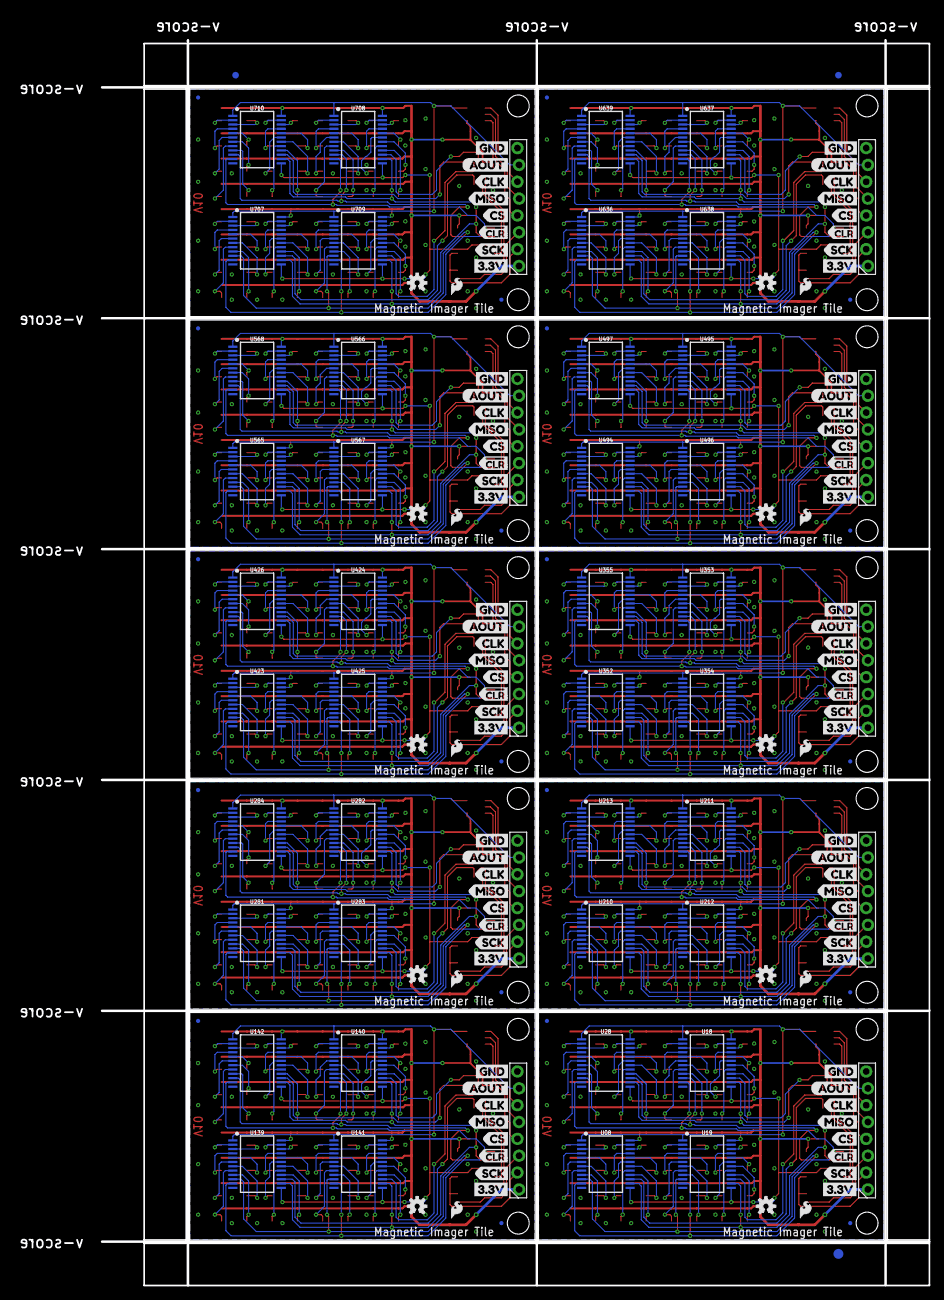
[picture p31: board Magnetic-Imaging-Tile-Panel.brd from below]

Board: 2 copper layers, 124.7 x 187.7 mm, 1016 parts (163 on the bottom side), 820 nets.

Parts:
C1, C2, C3, C4, C5, C6, C7, C8, C12, C13, C14, C15, C16, C17, C18, C19, C23, C24, C25, C26, C27, C28, C29, C30, C34, C35, C36, C37, C38, C39, C40, C41, C45, C46, C47, C48, C49, C50, C51, C52, C56, C57, C58, C59, C60, C61, C62, C63, C67, C68, C69, C70, C71, C72, C73, C74, C78, C79, C80, C81, C82, C83, C84, C85, C89, C90, C91, C92, C93, C94, C95, C96, C100, C101, C102, C103, C104, C105, C106, C107: 4.7uF; 0603
C9, C10, C11, C20, C21, C22, C31, C32, C33, C42, C43, C44, C53, C54, C55, C64, C65, C66, C75, C76, C77, C86, C87, C88, C97, C98, C99, C108, C109, C110: 0.1uF; 0603
E$1, E$2, E$3, E$4: FIDUCIAL-1X2
E$5, E$6: FIDUCIAL-1.5X3
FD1, FD2, FD3, FD4, FD5, FD6, FD7, FD8, FD9, FD10, FD11, FD12, FD13, FD14, FD15, FD16, FD17, FD18, FD19, FD20, FD21, FD22, FD23, FD24, FD25, FD26, FD27, FD28, FD29, FD30, FD31, FD32, FD33, FD34, FD35, FD36, FD37, FD38, FD39, FD40: FIDUCIALUFIDUCIAL; FIDUCIAL-MICRO
H1, H2, H3, H4, H5, H6, H7, H8, H9, H10, H11, H12, H13, H14, H15, H16, H17, H18, H19, H20: STAND-OFF
J1, J2, J3, J4, J5, J6, J7, J8, J9, J10: 1X08_LOCK_NO_SILK
LOGO1, LOGO3, LOGO5, LOGO7, LOGO9, LOGO11, LOGO13, LOGO15, LOGO17, LOGO19: SFE_LOGO_NAME.1_INCH; SFE_LOGO_NAME_.1
LOGO2, LOGO4, LOGO6, LOGO8, LOGO10, LOGO12, LOGO14, LOGO16, LOGO18, LOGO20: OSHW-LOGOS; OSHW-LOGO-S
U01, U02, U03, U04, U05, U06, U07, U09, U10, U11, U12, U13, U14, U15, U16, U17, U20, U21, U22, U23, U24, U25, U26, U27, U29, U30, U31, U32, U33, U34, U35, U36, U37, U38, U39, U40, U41, U42, U43, U44, U45, U46, U47, U48, U49, U50, U51, U52, U53, U54, U55, U56, U57, U58, U59, U60, U61, U62, U63, U64, U65, U66, U67, U68, U69, U70, U71, U72, U73, U74, U75, U76, U77, U78, U79, U80, U81, U82, U83, U84, U85, U86, U87, U88, U89, U90, U91, U92, U93, U94, U95, U96, U97, U98, U99, U100, U101, U102, U103, U107, U108, U109, U110, U111, U112, U113, U114, U115, U116, U117, U118, U119, U120, U121, U122, U123, U124, U125, U126, U127, U128, U129, U130, U131, U132, U133, U134, U138, U143, U144, U145, U146, U147, U148, U149, U150, U151, U152, U153, U154, U155, U156, U157, U158, U159, U160, U161, U162, U163, U164, U165, U166, U167, U168, U169, U170, U171, U172, U173, U174, U175, U176, U177, U178, U179, U180, U181, U182, U183, U184, U185, U186, U187, U188, U189, U190, U191, U192, U193, U194, U195, U196, U197, U198, U199, U200, U201, U202, U203, U204, U205, U209, U214, U215, U216, U217, U218, U219, U220, U221, U222, U223, U224, U225, U226, U227, U228, U229, U230, U231, U232, U233, U234, U235, U236, U237, U238, U239, U240, U241, U242, U243, U244, U245, U246, U247, U248, U249, U250, U251, U252, U253, U254, U255, U256, U257, U258, U259, U260, U261, U262, U263, U264, U265, U266, U267, U268, U269, U270, U271, U272, U273, U274, U275, U276, U280, U285, U286, U287, U288, U289, U290, U291, U292, U293, U294, U295, U296, U297, U298, U299, U300, U301, U302, U303, U304, U305, U306, U307, U308, U309, U310, U311, U312, U313, U314, U315, U316, U317, U318, U319, U320, U321, U322, U323, U324, U325, U326, U327, U328, U329, U330, U331, U332, U333, U334, U335, U336, U337, U338, U339, U340, U341, U342, U343, U344, U345, U346, U347, U351, U356, U357, U358, U359, U360, U361, U362, U363, U364, U365, U366, U367, U368, U369, U370, U371, U372, U373, U374, U375, U376, U377, U378, U379, U380, U381, U382, U383, U384, U385, U386, U387, U388, U389, U390, U391, U392, U393, U394, U395, U396, U397, U398, U399, U400, U401, U402, U403, U404, U405, U406, U407, U408, U409, U410, U411, U412, U413, U414, U415, U416, U417, U418, U422, U427, U428, U429, U430, U431, U432, U433, U434, U435, U436, U437, U438, U439, U440, U441, U442, U443, U444, U445, U446, U447, U448, U449, U450, U451, U452, U453, U454, U455, U456, U457, U458, U459, U460, U461, U462, U463, U464, U465, U466, U467, U468, U469, U470, U471, U472, U473, U474, U475, U476, U477, U478, U479, U480, U481, U482, U483, U484, U485, U486, U487, U488, U489, U493, U498, U499, U500, U501, U502, U503, U504, U505, U506, U507, U508, U509, U510, U511, U512, U513, U514, U515, U516, U517, U518, U519, U520, U521, U522, U523, U524, U525, U526, U527, U528, U529, U530, U531, U532, U533, U534, U535, U536, U537, U538, U539, U540, U541, U542, U543, U544, U545, U546, U547, U548, U549, U550, U551, U552, U553, U554, U555, U556, U557, U558, U559, U560, U564, U569, U570, U571, U572, U573, U574, U575, U576, U577, U578, U579, U580, U581, U582, U583, U584, U585, U586, U587, U588, U589, U590, U591, U592, U593, U594, U595, U596, U597, U598, U599, U600, U601, U602, U603, U604, U605, U606, U607, U608, U609, U610, U611, U612, U613, U614, U615, U616, U617, U618, U619, U620, U621, U622, U623, U624, U625, U626, U627, U628, U629, U630, U631, U635, U640, U641, U642, U643, U644, U645, U646, U647, U648, U649, U650, U651, U652, U653, U654, U655, U656, U657, U658, U659, U660, U661, U662, U663, U664, U665, U666, U667, U668, U669, U670, U671, U672, U673, U674, U675, U676, U677, U678, U679, U680, U681, U682, U683, U684, U685, U686, U687, U688, U689, U690, U691, U692, U693, U694, U695, U696, U697, U698, U699, U700, U701, U702, U706: DRV5053; SOT23-3
U08, U18, U19, U28, U139, U140, U141, U142, U210, U211, U212, U213, U281, U282, U283, U284, U352, U353, U354, U355, U423, U424, U425, U426, U494, U495, U496, U497, U565, U566, U567, U568, U636, U637, U638, U639, U707, U708, U709, U710: CD74HC4067; SSOP24
U104, U137, U208, U279, U350, U421, U492, U563, U634, U705: SN74HC590A; SO16
U105, U136, U207, U278, U349, U420, U491, U562, U633, U704: SN74LVC1G139; SM8
U106, U135, U206, U277, U348, U419, U490, U561, U632, U703: AD7680; SOT23-6
U$1, U$2, U$19, U$20, U$29, U$30, U$39, U$40, U$49, U$50, U$59, U$60, U$69, U$70, U$79, U$80, U$89, U$90, U$99, U$100: SFE_LOGO_FLAME_.1
U$3, U$11, U$21, U$31, U$41, U$51, U$61, U$71, U$81, U$91: GND
U$4, U$17, U$27, U$37, U$47, U$57, U$67, U$77, U$87, U$97: #CLR
U$5, U$12, U$22, U$32, U$42, U$52, U$62, U$72, U$82, U$92: 3#3V
U$6, U$13, U$23, U$33, U$43, U$53, U$63, U$73, U$83, U$93: AOUT
U$7, U$14, U$24, U$34, U$44, U$54, U$64, U$74, U$84, U$94: CLK
U$8, U$15, U$25, U$35, U$45, U$55, U$65, U$75, U$85, U$95: MISO
U$9, U$16, U$26, U$36, U$46, U$56, U$66, U$76, U$86, U$96: SCK
U$10, U$18, U$28, U$38, U$48, U$58, U$68, U$78, U$88, U$98: CS

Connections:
1I0: U18.9, U32.2
1I1: U18.8, U33.2
1I2: U18.7, U22.2
1I3: U18.6, U23.2
1I4: U12.2, U18.5
1I5: U13.2, U18.4
1I6: U02.2, U18.3
1I7: U03.2, U18.2
1I8: U01.2, U18.23
1I9: U09.2, U18.22
1I10: U11.2, U18.21
1I11: U10.2, U18.20
1I12: U18.19, U21.2
1I13: U18.18, U20.2
1I14: U18.17, U31.2
1I15: U18.16, U30.2
1I16: U87.2, U140.9
1I17: U95.2, U140.8
1I18: U86.2, U140.7
1I19: U94.2, U140.6
1I20: U85.2, U140.5
1I21: U93.2, U140.4
1I22: U84.2, U140.3
1I23: U92.2, U140.2
1I24: U68.2, U140.23
1I25: U138.2, U140.22
1I26: U69.2, U140.21
1I27: U29.2, U140.20
1I28: U78.2, U140.19
1I29: U38.2, U140.18
1I30: U79.2, U140.17
1I31: U39.2, U140.16
1I32: U161.2, U211.9
1I33: U169.2, U211.8
1I34: U160.2, U211.7
1I35: U168.2, U211.6
1I36: U159.2, U211.5
1I37: U167.2, U211.4
1I38: U158.2, U211.3
1I39: U166.2, U211.2
1I40: U150.2, U211.23
1I41: U209.2, U211.22
1I42: U151.2, U211.21
1I43: U143.2, U211.20
1I44: U152.2, U211.19
1I45: U144.2, U211.18
1I46: U153.2, U211.17
1I47: U145.2, U211.16
1I48: U232.2, U282.9
1I49: U240.2, U282.8
1I50: U231.2, U282.7
1I51: U239.2, U282.6
1I52: U230.2, U282.5
1I53: U238.2, U282.4
1I54: U229.2, U282.3
1I55: U237.2, U282.2
1I56: U221.2, U282.23
1I57: U280.2, U282.22
1I58: U222.2, U282.21
1I59: U214.2, U282.20
1I60: U223.2, U282.19
1I61: U215.2, U282.18
1I62: U224.2, U282.17
1I63: U216.2, U282.16
1I64: U303.2, U353.9
1I65: U311.2, U353.8
1I66: U302.2, U353.7
1I67: U310.2, U353.6
1I68: U301.2, U353.5
1I69: U309.2, U353.4
1I70: U300.2, U353.3
1I71: U308.2, U353.2
1I72: U292.2, U353.23
1I73: U351.2, U353.22
1I74: U293.2, U353.21
1I75: U285.2, U353.20
1I76: U294.2, U353.19
1I77: U286.2, U353.18
1I78: U295.2, U353.17
1I79: U287.2, U353.16
1I80: U374.2, U424.9
1I81: U382.2, U424.8
1I82: U373.2, U424.7
1I83: U381.2, U424.6
1I84: U372.2, U424.5
1I85: U380.2, U424.4
1I86: U371.2, U424.3
1I87: U379.2, U424.2
1I88: U363.2, U424.23
1I89: U422.2, U424.22
1I90: U364.2, U424.21
1I91: U356.2, U424.20
1I92: U365.2, U424.19
1I93: U357.2, U424.18
1I94: U366.2, U424.17
1I95: U358.2, U424.16
1I96: U445.2, U495.9
1I97: U453.2, U495.8
1I98: U444.2, U495.7
1I99: U452.2, U495.6
1I100: U443.2, U495.5
1I101: U451.2, U495.4
1I102: U442.2, U495.3
1I103: U450.2, U495.2
1I104: U434.2, U495.23
1I105: U493.2, U495.22
1I106: U435.2, U495.21
1I107: U427.2, U495.20
1I108: U436.2, U495.19
1I109: U428.2, U495.18
1I110: U437.2, U495.17
1I111: U429.2, U495.16
1I112: U516.2, U566.9
1I113: U524.2, U566.8
1I114: U515.2, U566.7
1I115: U523.2, U566.6
1I116: U514.2, U566.5
1I117: U522.2, U566.4
1I118: U513.2, U566.3
1I119: U521.2, U566.2
1I120: U505.2, U566.23
1I121: U564.2, U566.22
1I122: U506.2, U566.21
1I123: U498.2, U566.20
1I124: U507.2, U566.19
1I125: U499.2, U566.18
1I126: U508.2, U566.17
1I127: U500.2, U566.16
1I128: U587.2, U637.9
1I129: U595.2, U637.8
1I130: U586.2, U637.7
1I131: U594.2, U637.6
1I132: U585.2, U637.5
1I133: U593.2, U637.4
1I134: U584.2, U637.3
1I135: U592.2, U637.2
1I136: U576.2, U637.23
1I137: U635.2, U637.22
1I138: U577.2, U637.21
1I139: U569.2, U637.20
1I140: U578.2, U637.19
1I141: U570.2, U637.18
1I142: U579.2, U637.17
1I143: U571.2, U637.16
1I144: U658.2, U708.9
1I145: U666.2, U708.8
1I146: U657.2, U708.7
1I147: U665.2, U708.6
1I148: U656.2, U708.5
1I149: U664.2, U708.4
1I150: U655.2, U708.3
1I151: U663.2, U708.2
1I152: U647.2, U708.23
1I153: U706.2, U708.22
1I154: U648.2, U708.21
1I155: U640.2, U708.20
1I156: U649.2, U708.19
1I157: U641.2, U708.18
1I158: U650.2, U708.17
1I159: U642.2, U708.16
2I0: U19.9, U72.2
2I1: U19.8, U73.2
2I2: U19.7, U62.2
2I3: U19.6, U63.2
2I4: U19.5, U52.2
2I5: U19.4, U53.2
2I6: U19.3, U42.2
2I7: U19.2, U43.2
2I8: U19.23, U41.2
2I9: U19.22, U40.2
2I10: U19.21, U51.2
2I11: U19.20, U50.2
2I12: U19.19, U61.2
2I13: U19.18, U60.2
2I14: U19.17, U71.2
2I15: U19.16, U70.2
2I16: U91.2, U141.9
2I17: U99.2, U141.8
2I18: U90.2, U141.7
2I19: U98.2, U141.6
2I20: U89.2, U141.5
2I21: U97.2, U141.4
2I22: U88.2, U141.3
2I23: U96.2, U141.2
2I24: U80.2, U141.23
2I25: U48.2, U141.22
2I26: U81.2, U141.21
2I27: U49.2, U141.20
2I28: U82.2, U141.19
2I29: U58.2, U141.18
2I30: U83.2, U141.17
2I31: U59.2, U141.16
2I32: U165.2, U212.9
2I33: U173.2, U212.8
2I34: U164.2, U212.7
2I35: U172.2, U212.6
2I36: U163.2, U212.5
2I37: U171.2, U212.4
2I38: U162.2, U212.3
2I39: U170.2, U212.2
2I40: U154.2, U212.23
2I41: U146.2, U212.22
2I42: U155.2, U212.21
2I43: U147.2, U212.20
2I44: U156.2, U212.19
2I45: U148.2, U212.18
2I46: U157.2, U212.17
2I47: U149.2, U212.16
2I48: U236.2, U283.9
2I49: U244.2, U283.8
2I50: U235.2, U283.7
2I51: U243.2, U283.6
2I52: U234.2, U283.5
2I53: U242.2, U283.4
2I54: U233.2, U283.3
2I55: U241.2, U283.2
2I56: U225.2, U283.23
2I57: U217.2, U283.22
2I58: U226.2, U283.21
2I59: U218.2, U283.20
2I60: U227.2, U283.19
2I61: U219.2, U283.18
2I62: U228.2, U283.17
2I63: U220.2, U283.16
2I64: U307.2, U354.9
2I65: U315.2, U354.8
2I66: U306.2, U354.7
2I67: U314.2, U354.6
2I68: U305.2, U354.5
2I69: U313.2, U354.4
2I70: U304.2, U354.3
2I71: U312.2, U354.2
2I72: U296.2, U354.23
2I73: U288.2, U354.22
2I74: U297.2, U354.21
2I75: U289.2, U354.20
2I76: U298.2, U354.19
2I77: U290.2, U354.18
2I78: U299.2, U354.17
2I79: U291.2, U354.16
2I80: U378.2, U425.9
2I81: U386.2, U425.8
2I82: U377.2, U425.7
2I83: U385.2, U425.6
2I84: U376.2, U425.5
2I85: U384.2, U425.4
2I86: U375.2, U425.3
2I87: U383.2, U425.2
2I88: U367.2, U425.23
2I89: U359.2, U425.22
2I90: U368.2, U425.21
2I91: U360.2, U425.20
2I92: U369.2, U425.19
2I93: U361.2, U425.18
2I94: U370.2, U425.17
2I95: U362.2, U425.16
2I96: U449.2, U496.9
2I97: U457.2, U496.8
2I98: U448.2, U496.7
2I99: U456.2, U496.6
2I100: U447.2, U496.5
2I101: U455.2, U496.4
2I102: U446.2, U496.3
2I103: U454.2, U496.2
2I104: U438.2, U496.23
2I105: U430.2, U496.22
2I106: U439.2, U496.21
2I107: U431.2, U496.20
2I108: U440.2, U496.19
2I109: U432.2, U496.18
2I110: U441.2, U496.17
2I111: U433.2, U496.16
2I112: U520.2, U567.9
2I113: U528.2, U567.8
2I114: U519.2, U567.7
2I115: U527.2, U567.6
2I116: U518.2, U567.5
2I117: U526.2, U567.4
2I118: U517.2, U567.3
2I119: U525.2, U567.2
2I120: U509.2, U567.23
2I121: U501.2, U567.22
2I122: U510.2, U567.21
2I123: U502.2, U567.20
2I124: U511.2, U567.19
2I125: U503.2, U567.18
2I126: U512.2, U567.17
2I127: U504.2, U567.16
2I128: U591.2, U638.9
2I129: U599.2, U638.8
2I130: U590.2, U638.7
2I131: U598.2, U638.6
2I132: U589.2, U638.5
2I133: U597.2, U638.4
2I134: U588.2, U638.3
2I135: U596.2, U638.2
2I136: U580.2, U638.23
2I137: U572.2, U638.22
2I138: U581.2, U638.21
2I139: U573.2, U638.20
2I140: U582.2, U638.19
2I141: U574.2, U638.18
2I142: U583.2, U638.17
2I143: U575.2, U638.16
2I144: U662.2, U709.9
2I145: U670.2, U709.8
2I146: U661.2, U709.7
2I147: U669.2, U709.6
2I148: U660.2, U709.5
2I149: U668.2, U709.4
2I150: U659.2, U709.3
2I151: U667.2, U709.2
2I152: U651.2, U709.23
2I153: U643.2, U709.22
2I154: U652.2, U709.21
2I155: U644.2, U709.20
2I156: U653.2, U709.19
2I157: U645.2, U709.18
2I158: U654.2, U709.17
2I159: U646.2, U709.16
3.3V: C1.1, C2.1, C3.1, C4.1, C5.1, C6.1, C7.1, C8.1, C9.1, C10.1, C11.1, J1.1, U01.1, U02.1, U03.1, U04.1, U05.1, U06.1, U07.1, U08.24, U09.1, U10.1, U11.1, U12.1, U13.1, U14.1, U15.1, U16.1, U17.1, U18.24, U19.24, U20.1, U21.1, U22.1, U23.1, U24.1, U25.1, U26.1, U27.1, U28.24, U30.1, U31.1, U32.1, U33.1, U34.1, U35.1, U36.1, U37.1, U40.1, U41.1, U42.1, U43.1, U44.1, U45.1, U46.1, U47.1, U50.1, U51.1, U52.1, U53.1, U54.1, U55.1, U56.1, U57.1, U60.1, U61.1, U62.1, U63.1, U64.1, U65.1, U66.1, U67.1, U70.1, U71.1, U72.1, U73.1, U74.1, U75.1, U76.1, U77.1, U104.16, U105.8, U106.1
3.3V1: C12.1, C13.1, C14.1, C15.1, C16.1, C17.1, C18.1, C19.1, C20.1, C21.1, C22.1, J2.1, U29.1, U38.1, U39.1, U48.1, U49.1, U58.1, U59.1, U68.1, U69.1, U78.1, U79.1, U80.1, U81.1, U82.1, U83.1, U84.1, U85.1, U86.1, U87.1, U88.1, U89.1, U90.1, U91.1, U92.1, U93.1, U94.1, U95.1, U96.1, U97.1, U98.1, U99.1, U100.1, U101.1, U102.1, U103.1, U107.1, U108.1, U109.1, U110.1, U111.1, U112.1, U113.1, U114.1, U115.1, U116.1, U117.1, U118.1, U119.1, U120.1, U121.1, U122.1, U123.1, U124.1, U125.1, U126.1, U127.1, U128.1, U129.1, U130.1, U131.1, U132.1, U133.1, U134.1, U135.1, U136.8, U137.16, U138.1, U139.24, U140.24, U141.24, U142.24
3.3V2: C23.1, C24.1, C25.1, C26.1, C27.1, C28.1, C29.1, C30.1, C31.1, C32.1, C33.1, J3.1, U143.1, U144.1, U145.1, U146.1, U147.1, U148.1, U149.1, U150.1, U151.1, U152.1, U153.1, U154.1, U155.1, U156.1, U157.1, U158.1, U159.1, U160.1, U161.1, U162.1, U163.1, U164.1, U165.1, U166.1, U167.1, U168.1, U169.1, U170.1, U171.1, U172.1, U173.1, U174.1, U175.1, U176.1, U177.1, U178.1, U179.1, U180.1, U181.1, U182.1, U183.1, U184.1, U185.1, U186.1, U187.1, U188.1, U189.1, U190.1, U191.1, U192.1, U193.1, U194.1, U195.1, U196.1, U197.1, U198.1, U199.1, U200.1, U201.1, U202.1, U203.1, U204.1, U205.1, U206.1, U207.8, U208.16, U209.1, U210.24, U211.24, U212.24, U213.24
3.3V3: C34.1, C35.1, C36.1, C37.1, C38.1, C39.1, C40.1, C41.1, C42.1, C43.1, C44.1, J4.1, U214.1, U215.1, U216.1, U217.1, U218.1, U219.1, U220.1, U221.1, U222.1, U223.1, U224.1, U225.1, U226.1, U227.1, U228.1, U229.1, U230.1, U231.1, U232.1, U233.1, U234.1, U235.1, U236.1, U237.1, U238.1, U239.1, U240.1, U241.1, U242.1, U243.1, U244.1, U245.1, U246.1, U247.1, U248.1, U249.1, U250.1, U251.1, U252.1, U253.1, U254.1, U255.1, U256.1, U257.1, U258.1, U259.1, U260.1, U261.1, U262.1, U263.1, U264.1, U265.1, U266.1, U267.1, U268.1, U269.1, U270.1, U271.1, U272.1, U273.1, U274.1, U275.1, U276.1, U277.1, U278.8, U279.16, U280.1, U281.24, U282.24, U283.24, U284.24
3.3V4: C45.1, C46.1, C47.1, C48.1, C49.1, C50.1, C51.1, C52.1, C53.1, C54.1, C55.1, J5.1, U285.1, U286.1, U287.1, U288.1, U289.1, U290.1, U291.1, U292.1, U293.1, U294.1, U295.1, U296.1, U297.1, U298.1, U299.1, U300.1, U301.1, U302.1, U303.1, U304.1, U305.1, U306.1, U307.1, U308.1, U309.1, U310.1, U311.1, U312.1, U313.1, U314.1, U315.1, U316.1, U317.1, U318.1, U319.1, U320.1, U321.1, U322.1, U323.1, U324.1, U325.1, U326.1, U327.1, U328.1, U329.1, U330.1, U331.1, U332.1, U333.1, U334.1, U335.1, U336.1, U337.1, U338.1, U339.1, U340.1, U341.1, U342.1, U343.1, U344.1, U345.1, U346.1, U347.1, U348.1, U349.8, U350.16, U351.1, U352.24, U353.24, U354.24, U355.24
3.3V5: C56.1, C57.1, C58.1, C59.1, C60.1, C61.1, C62.1, C63.1, C64.1, C65.1, C66.1, J6.1, U356.1, U357.1, U358.1, U359.1, U360.1, U361.1, U362.1, U363.1, U364.1, U365.1, U366.1, U367.1, U368.1, U369.1, U370.1, U371.1, U372.1, U373.1, U374.1, U375.1, U376.1, U377.1, U378.1, U379.1, U380.1, U381.1, U382.1, U383.1, U384.1, U385.1, U386.1, U387.1, U388.1, U389.1, U390.1, U391.1, U392.1, U393.1, U394.1, U395.1, U396.1, U397.1, U398.1, U399.1, U400.1, U401.1, U402.1, U403.1, U404.1, U405.1, U406.1, U407.1, U408.1, U409.1, U410.1, U411.1, U412.1, U413.1, U414.1, U415.1, U416.1, U417.1, U418.1, U419.1, U420.8, U421.16, U422.1, U423.24, U424.24, U425.24, U426.24
3.3V6: C67.1, C68.1, C69.1, C70.1, C71.1, C72.1, C73.1, C74.1, C75.1, C76.1, C77.1, J7.1, U427.1, U428.1, U429.1, U430.1, U431.1, U432.1, U433.1, U434.1, U435.1, U436.1, U437.1, U438.1, U439.1, U440.1, U441.1, U442.1, U443.1, U444.1, U445.1, U446.1, U447.1, U448.1, U449.1, U450.1, U451.1, U452.1, U453.1, U454.1, U455.1, U456.1, U457.1, U458.1, U459.1, U460.1, U461.1, U462.1, U463.1, U464.1, U465.1, U466.1, U467.1, U468.1, U469.1, U470.1, U471.1, U472.1, U473.1, U474.1, U475.1, U476.1, U477.1, U478.1, U479.1, U480.1, U481.1, U482.1, U483.1, U484.1, U485.1, U486.1, U487.1, U488.1, U489.1, U490.1, U491.8, U492.16, U493.1, U494.24, U495.24, U496.24, U497.24
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

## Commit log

2024-07-11 Initial commit
    -Pulled files from spx repo
    -Updated silk
    [Magnetic-Imaging-Tile.brd, Magnetic-Imaging-Tile.sch]
2024-07-11 Silk Update
    Removed name and date from old design
    [Magnetic-Imaging-Tile.brd]
2024-07-12 Update
    -Changes silk to vector
    -Added order instructions
    -Updated Design By
    -OSH and SPARKFUN added to sch and board as part
    [Magnetic-Imaging-Tile.brd, Magnetic-Imaging-Tile.sch]
2024-07-19 Add v10 production files
    [Magnetic-Imaging-Tile-Panel.GBL, Magnetic-Imaging-Tile-Panel.GBO, Magnetic-Imaging-Tile-Panel.GBP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]

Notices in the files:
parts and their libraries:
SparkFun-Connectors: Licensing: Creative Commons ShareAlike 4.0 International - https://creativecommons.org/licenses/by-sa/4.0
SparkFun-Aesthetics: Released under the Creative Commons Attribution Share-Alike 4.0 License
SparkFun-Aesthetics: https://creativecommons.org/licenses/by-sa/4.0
